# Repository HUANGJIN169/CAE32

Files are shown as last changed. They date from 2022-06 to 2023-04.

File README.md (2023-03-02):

# CAE32

CAE32 es un proyecto de construcción y desarrollo de todas las etapas de un volante para videojuegos de PC,
para el sistema operativo de GNU/Linux.

## Las etapas son:

* Diseño PCB
* Firmware
* Driver (Kernel module)
* Configuración y calibración por medio de una interfaz de usuario (GTK-3)
* Diseño de mecanismos para pedales, palanca de cambios y volante
* Diseño PCB de potencia para el control del motor de retroalimentación (FFB)

## Descripción detallada

### Microcontroladores

Para esta primera versión de Harware, se crean 3 PCB

1. Placa principal (ESP32-S3)
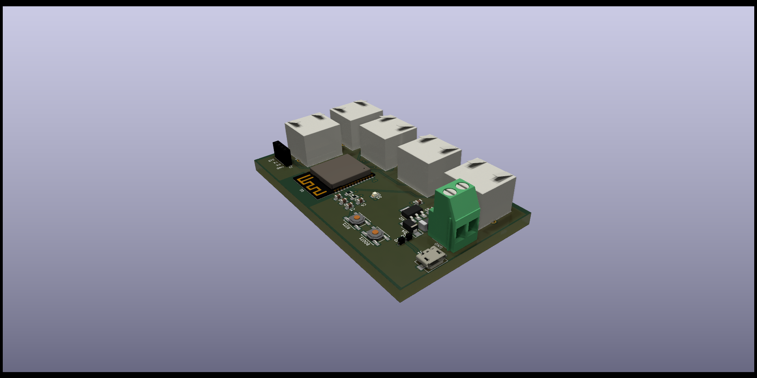
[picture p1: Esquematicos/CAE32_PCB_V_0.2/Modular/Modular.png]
Modular

2. Placa para la captura de señales analogicas (STM32G070KBT6)
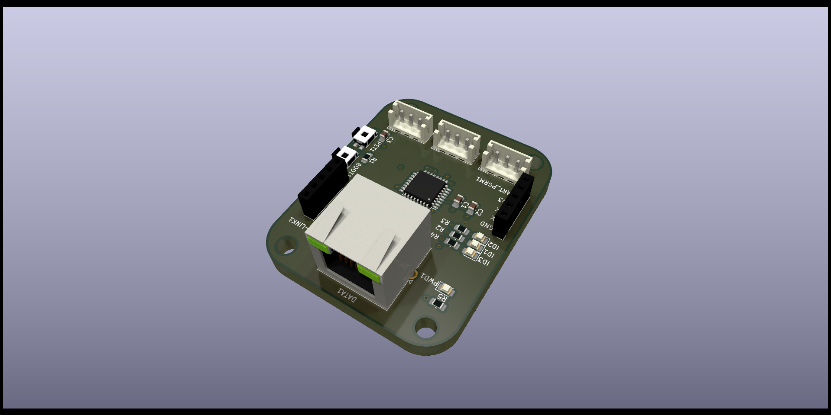
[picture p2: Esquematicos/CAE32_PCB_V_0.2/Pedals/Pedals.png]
Señales

3. Placa con el sensor hall (MT9105ET)
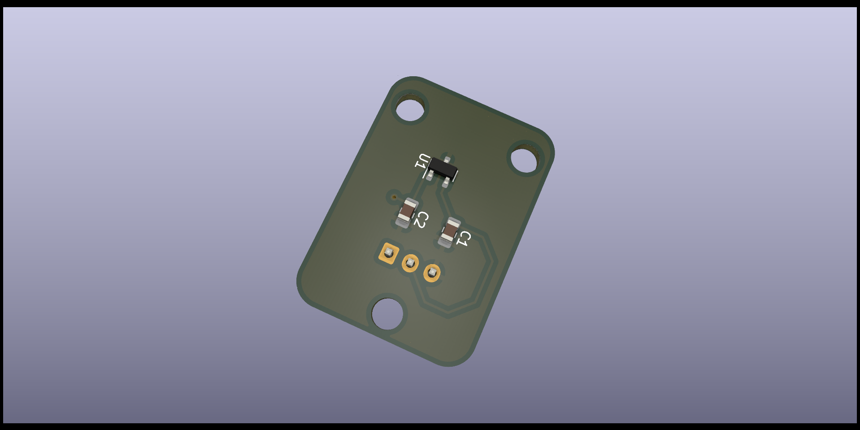
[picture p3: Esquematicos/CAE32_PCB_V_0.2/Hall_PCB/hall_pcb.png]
hall


### Firmware

Estoy usando el framework de Espressif (ESP-IDF)

Se usa el microcontrolador STM32G070KBT6, en conjunto con el software
STM32CubeIDE y para programarlo es necesario la utilidad STM32CubeProgrammer,
ademas de una conexión con un "USB-UART bridge"

### Interfaz de usuario

La interfaz está desarrollada con el framework (GTK 3), esta permitirá hacer configuraciones, como por ejemplo:

* Visualización de los datos gráficamente y textual (consola)
* Tipo de transmisión (Manual, Automática, Secuencial, custom) **De forma nativa**
* Límites de los pedales, sensibilidad 
* Tipo de pedal
	* Entrada analógica (Potenciómetro, efecto hall)
	* Entrada SPI,I2c (Célula de carga)
* Actualización de firmware

Diseño de interfaz hasta el momento.

**Para compilar el proyecto puedes usar el contenedor o construirlo en tu sistema(cumpliendo con las dependencias),
revisa la wiki para mas información**

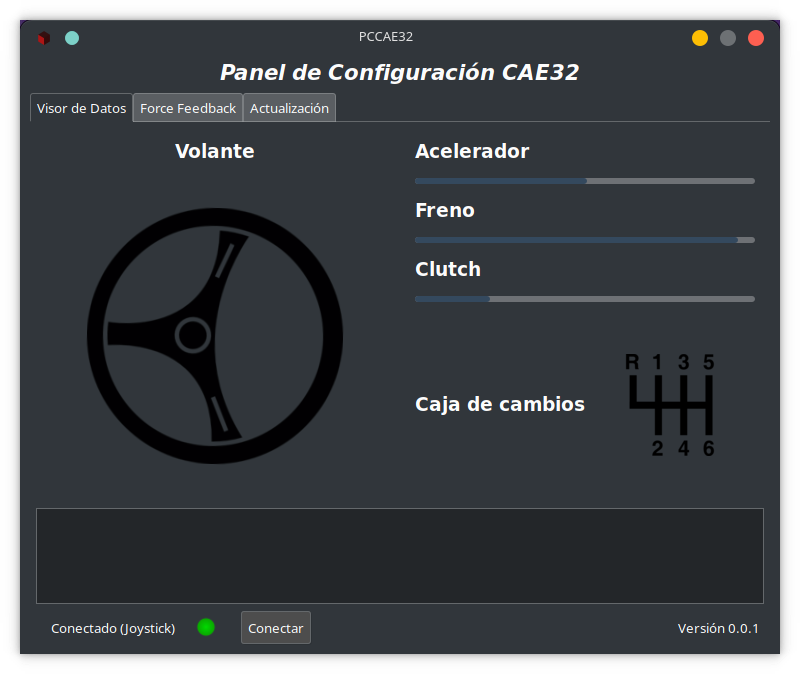
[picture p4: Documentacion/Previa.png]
interfaz


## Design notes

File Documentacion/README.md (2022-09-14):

# Descripción general para simular el movimiento de pedales
* El objetivo de realizar este componente(indicador de grados) es para hacer pruebas automatizadas. Haciendo una simulación de los movimientos realizados a la hora de conducir
* Con una retroalimentación tanto como física como digital (Mostrando los valores en la terminal)
* Ademas en el futuro este mismo componente se podría usar para mostrar las revoluciones del motor o velocidad, en general el estado de alguna características del auto
## Pasos para simular "pedales" 

### 1. Configurar el encoder magnético (AS5600) que se encarga de obtener el angulo del iman 
- Este encoder se programa por medio de comunicación i2c para leer y escribir a diferentes registros
- Requiere de mover el indicador manualmente al angulo mínimo y máximo
### 2. Constantemente convertir el valor analógico a grados para conocer su posición
- Es necesario que siempre se este ejecutando una tarea que este revisando los grados actuales y compararlos con los grados deseados
### 3. Controlar el motor DC
- Como el motor simulara el movimiento, por ejemplo, el del un volante, este tiene que girar en un sentido o en el otro, con diferentes velocidades y cambios repentinos de sentido de giro
- Se puede aplicar un control PID

## [Materiales necesarios para crear este componente](Hardware%20componentes%20eléctricos/Indicador%20de%20grados.md)
## [Obtención de grados](Firmware/Obtención%20de%20grados.md)

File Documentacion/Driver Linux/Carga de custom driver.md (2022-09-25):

https://stackoverflow.com/questions/37427731/use-custom-driver-over-an-existing-driver
https://docs.kernel.org/driver-api/usb/writing_usb_driver.html
https://docs.kernel.org/driver-api/driver-model/binding.html

## USB Host-Side API Model[¶](https://docs.kernel.org/driver-api/usb/usb.html#usb-host-side-api-model "Permalink to this heading")
Host-side drivers for USB devices talk to the “usbcore”

USB device drivers actually bind to interfaces, not devices. Think of them as “interface drivers”, though you may not see many devices where the distinction is important. _Most USB devices are simple, with only one function, one configuration, one interface, and one alternate setting._

-   The Linux USB API supports synchronous calls for control and bulk messages. It also supports asynchronous calls for all kinds of data transfer, using request structures called “URBs” (USB Request Blocks).

In `include/uapi/linux/usb/ch9.h` you will find the USB data types defined in chapter 9 of the USB specification. These data types are used throughout USB, and in APIs including this host side API, gadget APIs, usb character devices and debugfs interfaces. That file is itself included by `include/linux/usb/ch9.h`, which also contains declarations of a few utility routines for manipulating these data types; the implementations are in `drivers/usb/common/common.c`.

### /dev/bus/usb/BBB/DDD[¶](https://docs.kernel.org/driver-api/usb/usb.html#dev-bus-usb-bbb-ddd "Permalink to this heading")

Use these files in one of these basic ways:

-   _They can be read,_ producing first the device descriptor (18 bytes) and then the descriptors for the current configuration. See the USB 2.0 spec for details about those binary data formats. You’ll need to convert most multibyte values from little endian format to your native host byte order, although a few of the fields in the device descriptor (both of the BCD-encoded fields, and the vendor and product IDs) will be byteswapped for you. Note that configuration descriptors include descriptors for interfaces, altsettings, endpoints, and maybe additional class descriptors.
    
-   _Perform USB operations_ using _ioctl()_ requests to make endpoint I/O requests (synchronously or asynchronously) or manage the device. These requests need the `CAP_SYS_RAWIO` capability, as well as filesystem access permissions. Only one ioctl request can be made on one of these device files at a time. This means that if you are synchronously reading an endpoint from one thread, you won’t be able to write to a different endpoint from another thread until the read completes. This works for _half duplex_ protocols, but otherwise you’d use asynchronous i/o requests.

You could check this by changing your final `grep` into `grep --color=always` and piping into `hexdump`, which will show all the unprintable characters and the ones interpreted by your terminal.

In `include/uapi/linux/usb/ch9.h` you will find the USB data types defined in chapter 9 of the USB specification. These data types are used throughout USB, and in APIs including this host side API, gadget APIs, usb character devices and debugfs interfaces. That file is itself included by `include/linux/usb/ch9.h`, which also contains declarations of a few utility routines for manipulating these data types; the implementations are in `drivers/usb/common/common.c`.

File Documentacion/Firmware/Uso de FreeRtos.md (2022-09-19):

# FreeRtos
Para controlar el tiempo de ejecución de cada función es necesario usar FreeRtos, ya que se pueden crear tareas **(_Tasks_)** de manera periódicas además de añadirles un nivel de prioridad a cada una de estas.

**Nota:** Otra manera de manejar el orden de ejecución de funciones, es por medio de interrupciones, **Ejemplo:** se asigna una interrupción cuando se sobrecarga un temporizador **_(Timer)_**  para poder ejecutar una función sería algo equivalente a las tareas periódicas  .

## Las tareas que deben ejecutarse son las siguientes
1. Obtención del valor a enviar, en este caso los grados, pero para obtener mas precisión se usara el valor directo del ADC debido a abarca un rango mas amplio 0->4095 **8Bits** pero se puede aumentar hasta **11Bits**, mientras que los grados 0->360
2. Envió de la trama de datos por protocolo USB 
3. Recepción de datos para aplicar un feedback al volante
4. Aplicar el control PID al motor, con los datos recién recibidos 

|Número de tarea|Características|
|--|--|
|1|Debe de ejecutarse 4 veces consecutivamente cada cierto periodo de tiempo|
|2,3,4|Tarea periódica para tener un dispositivo sincrónico|
 
## Queue o no Queue
Parece que la mejor forma de pasar datos entre tareas es por medio de queues, ya que es menos probable que te des un disparo en el pie ya que no es necesario el uso de punteros, aunque también se pueden usar.

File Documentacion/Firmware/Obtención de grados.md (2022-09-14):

# Obtención de grados
### El encoder magnético ofrece 3 maneras de obtener el ángulo
* Comunicación i2c leyendo dos registros
* Variación de voltaje en el pin OUT proporcional al ángulo **Se usará esta opción**
* Variación de ciclo de trabajo en cada pulso que es proporcional al ángulo
### Para usar estas opciones es necesario realizar una configuración por medio de comunicación i2c
**Nota:** Es posible programarlo solo usando el pin OUT pero la configuración es casi nula

### Para obtener mas información de este encoder aquí esta la [hoja de datos del AS5600](https://datasheet.lcsc.com/lcsc/2004071505_AMS-AS5600-ASOT_C499458.pdf) 

## Proceso de configuración
La configuración para esta aplicación depende del movimiento de los pedales, normalmente no excede los **360°** (mas de una vuelta) de rotación, así que para aprovechar la mayor resolución (el valor obtenido se acercara mas al real) hay que usar solo el rango de grados necesario en este caso **260°** 

|N. Paso|Instrucciones|
|--|--|
|1|Seguir los pasos para limitar el rango máximo del angulo como se muestra [aquí](https://datasheet.lcsc.com/lcsc/2004071505_AMS-AS5600-ASOT_C499458.pdf#page=24) con un valor 2958 -> 1Bit **0B** 2Bit **8E** , estos valores se obtiene con esta [regla de 3](https://datasheet.lcsc.com/lcsc/2004071505_AMS-AS5600-ASOT_C499458.pdf#page=24)| 
|2|Seguir los pasos para elegir la posición inicial y final como se muestra [aquí](https://datasheet.lcsc.com/lcsc/2004071505_AMS-AS5600-ASOT_C499458.pdf#page=22)|
|3|Guardar la configuración permanente usando el el paso de BURN_ANGLE, mostrado en las referencias externas mostradas en los pasos anteriores|
|4|Los valores cargados para el registro CONF son: salida analógica en un rango de 10% a 90%, aunque todavía se podría mejorar la precisión haciendo unos cambios|

**Notas:** 
1. Este proceso se hace por medio de la comunicación i2c.
2. El paso numero 2 se puede hacer de dos maneras.
* Manualmente, moviendo el indicador a la parte inicial y final, en el arranque del ESP-32 presionando un botón 
* Automáticamente, usando el motor para que por un tiempo definido se mueva hasta un tope en la zona inicial, cambie de sentido y tope con la zona final 
3. El imán siempre debe de estar presente, de lo contrario no se guardaran los datos
4. Se elige un rango 10% a 90% por que el ADC del ESP-32 no puede leer voltaje menor a 0.1 V , además se usa un divisor de voltaje para disminuir el rango de voltaje superior y sea posible medir.
## Después de la configuración
**Conozco dos maneras de obtener los grados**
1. Usar interrupciones con ayuda de un timer para hacer la conversión de voltaje a grados y usar ese valor como entrada para el controlador PID
2. Usar FreeRtos y asignar como tarea,hacer la conversión de voltaje a grados para el PID
## [Aplicación de controlador PID](Control%20PID.md)
## [Uso de FreeRtos](Uso%20de%20FreeRtos.md)

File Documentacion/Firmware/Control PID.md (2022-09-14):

# Control PID
El controlador PID permitirá un control estable para apuntar a los grados deseados.

A grandes rasgos será una función que tome de entrada los grados actuales, aplique una ecuación y retorna una variable con la cual se podrá variar la velocidad del motor DC
>Ejemplo :
>Cuando se acerquen los grados actuales a los grados deseados, este disminuirá el ciclo de trabajo PWM(se puede interpretar como que disminuye la velocidad) y no sobrepasara los grados deseados

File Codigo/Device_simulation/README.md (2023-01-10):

# Device Class Definition for Human Interface Devices (HID) Version1.11

**Si queres ver como fue el desarrollo del driver y herramientas, te recomiendo que veas este [archivo](Bitácora.md)**

### Enlaces de información 

[Device Class Definition for Human Interface Devices (HID) Version1.11](https://www.usb.org/sites/default/files/hid1_11.pdf)
[HID Usage Tables FOR Universal Serial Bus (USB)](https://usb.org/sites/default/files/hut1_3_0.pdf)

- Debido a que es muy extenso la documentación relacioanad al descriptor de un dispositivo 
de interfaz humana, tomaré nota de cada tema y llenare los huecos tomando como ejemplo a CAE32

## Capacidades de CAE32

Descripción simple de como funcionan los sensores que se encuentran en un 
volante para videojuegos

### Palanca de cambios

En los autos reales solo existen dos estados en los que puede encontrar una velocidad:

* Velocidad acoplada
* Velocidad no acoplada

Esto se puede comparar con una señal digital la cual solo puede estar en dos estados "1" y "0"
lógico, con lo que se puede usar un botón 

**Nota:** Tecnicamente los estados en los que puede estar una transmisión estandar son: el numero
de velocidades del auto mas uno (neutral)

**Ejemplo: Transmisión de auto estandar de 8 velocidades representada en una trama de bits**

|bit|7|6|5|4|3|2|1|0|
|--|--|--|--|--|--|--|--|--|
|Estado|0|0|0|0|1|0|0|0|

Tomando en cuenta que el bit 0 es la reversa y la primera corresponde con el bit 1, segunda con
el bit 2, y así sucesivamente

Se entiende que se encuentra en la tercera marcha, y para identificar neutral sería que todas
las marchas se encuentren desacopladas, exactamente como en la vida real.

|bit|7|6|5|4|3|2|1|0|
|--|--|--|--|--|--|--|--|--|
|Estado|0|0|0|0|0|0|0|0|

### Pedales

Los pedales funcionan dependiendo en cuanta fuerza se aplique y el recorrido de estos

Por ejemplo si quisiera revolucionar el motor al 50% debo de presionar el acelerador hasta la mitad
del recorrido (en dado que este se comporte de manera lineal), 25%=1/4, 
54%=un poco mas de la mitad, etc.

**Ejemplo: Comportamiento del acelerador en relación con la velocidad elegida**

Pos

Y a que tipo de señal se compara en el mundo de la electrónica: a la señal analogica

**Ejemplo: Señal analógica en relación con el tiempo**

SenA

Y la forma en la que se representa en el mundo digital, es usando un ADC (Analog to DC converter),
el rango de valores que toma depende de su resolución que puede ir desde 8bits hasta 24bits o 
incluso mas, está resolución se podría notar en la sensibilidad de este, lo que se traduce a
un mayor control del auto

**Nota:** la resolución maxima y el formato permitido también depende del juego

**Ejemplo: Valor de un pedal representado en 8bits | Rango de valores (0,255)**

* Valor:183, equivalente a presionar 71% del recorrido total 

|bit|7|6|5|4|3|2|1|0|
|--|--|--|--|--|--|--|--|--|
|Estado|1|0|1|1|0|1|1|1|

### Volante

El comportamiento de un volante es similar al de un pedal, solo que este puede hacer transiciones,
con la diferencia que este puede o no tener un tope físico, esto depende del tipo de transductor
usado, este puede ser un potenciometro, sensor de efecto hall, etc

Desconozco como se toma el valor en el videojuego, lo mas seguro es que se comporte como un pedal,
donde 127 (con una resolución de 8bits) sea el centro y dependiendo de los grados de giro 
de elegidos (normalmente los volantes de entrada cuentan con 900°) los divide y por ejemplo una 
diferencia de 102 se toma como una vuelta completa.

## Resumen

El espacio en bits requeridos para el HID 
 
* 8 bits para la palanca de cambios | 1 bit por cada velocidad o 3 bits, reprentando el valor de la marcha en
binario **Ejemplo** Primera=0x001, Quinta=0x101, Ocatava=0x111 etc

* 32 bits para pedales y volante | 8 bits por cada pedal o volante 

# 5. Operational Model

## 5.1 Device Descriptor Structure

En el nivel mas alto, el descriptor incluye dos tablas

* Información referida al "Device Descriptor"
* Información referida al "String Descriptor"

La estructura de un descriptor principalmente se compone de 

- Class
- Subclass
- Vendor
- Product
- Version
 
Siguiendo este esquema

estructura 

Para un "HID class device" el tipo de "Class" no esta definido al nivel de "Device descriptor"
entonces la clase esta definida en el "Interface descriptor"

## 5.2 Report Descriptor

Aunque los Descriptores seán ilustrados con un diagrama de flujo estos en realidad estan compuestos
en piezas de información conocidos como "Item" 

Un "Item" es una pieza unica de información

## 5.3 Generic Item Format

Un "Item" es un pieza de información acerca del dispositivo, todos los "items" tienen un prefijo del
tamaño de un byte y contiene "item tag, item type, item size" etiqueta, tipo y tamaño

|bits|23-16|15-8|7-0|
|--|--|--|--|
|Partes|[data]|[data]|btag,btype,bsize|
|Bytes|2|1|0|

Un "Item" puede contener "optional item data", el tamaño de la porcion de la "data" de un "item"
esta determinada por el tipo fundamental de dato, existen dos tipos basicos de "item": "short and
long", si un item es corto, "its optional data size may be 0,1,2 or 4 bytes" si un item es largo
el valor de bSize siempre sera 2

**Ejemplo**

|bits|258-24|23-16|15-8|70|
|--|--|--|--|--|
|Partes|[data]|blongItemTag|bDataSize|111/11/10|
|Bytes|3-258|2|1|0|

## 5.4 Item Parser

EL controlador de clases del HID contiene un analizador (Parser) usado par encontrar "items" 
en el reporte de descripción

Este analizador colecta el estado de cada item conocido con forma avanza el descriptor,
y los guarda una tabla de estado de items

La tabla de estados de items contiene el estado de cada item individualmente

Desde el punto de vista del analizador, el dispositivo de clases HID se ve así

analizado

Cuando algunos items son encontrados, el contenido de la tabla de estados de items es movida,
estos items incluyen todos lo "Main,Push and Pop" items

Cuando un item "Main" es encontrado, una nueva estructura de reporte es alocada e inicializada
con la actual tabla de estado de items.

Todos los items Locales son removidos de la tabla de estados de items, pero los items Globales
se quedan, de esta forma los items globales definen los valores por defecto de los subsecuentes nuevos items Main

Un dispositivo con muchos controles similares, por ejemplo 6 ejes, necesitaría definir los items 
globales solo una vez en el primer item Main.

**Nota:** Los items Main son asociados con una colección en el orden que en los que ellos fueron
declarados, una nueva colección empieza cuando el analizador llega a un item de colección,
El analizador asocia una colección con todos los items Main definidos entre el item colección y 
el siguiente item fin de colección

Cuando un item Push es encotrado, la tabla de estado de items es copiado y colocada en el "stack"
para su futura recuperación

Cuando un item Pop es encontrado, la tabla de estado de items es remplazada con el "top table from
the stack" 

**Ejemplo**

`Unit (Meter), Unit Exponent (-3), Push, Unit Exponent (0)`

Cuando el analizador alcanza el item Push, coloca la unidad de los items en milimetros `10^-3 
metros`"on the stack", el siguiente item cambia el estado de item de la tabla a unidad de metros 
`10^0 metros`

El Analizador es requerido para analizar todo el reporte del descriptor para encontrar todos los 
items Main, esto es necesario en orden para analizar los reportes enviados por el dispositivo

## 5.5 Usages

Mientras un reporte de descriptor describe el formato de los datos

**Ejemplo** 3 campos de 8 bits

Una etiqueta "Usage" define que se debe de hacer con eso dato

**Ejemplo** entradas "x,y" y "z"

Un reporte de descriptor puede tener multiples etiquetas de "usages"

Existe una correspondencía una-a-una entre "usages" y controles, un control "usage" definido en el 
descriptor

Una matriz indica que cada campo del reporte del descriptor representa varios controles físicos 

Cada control quiza tenga atributos como "usage" asignados a ellos

**Ejemplo** una matriz de 4 botones puede tener una unica etiqueta "usage" por cada botón

Un "usage" es interpretado como un valor de 32 bits sin signo donde el mayor orden, los primeros
16 bits definen el "usage page" y los otros menores 16 bits definen la identificación del uso
"Usage ID" 

"Usage IDS" son usados para seleccionar "usages" individualmente en una "usage Page"

## 5.6 Reports

Una reporte es sinonimo de transferencía
 
Una transferencía quiza se compone de multiple paquetes con un maximo de 
* 8bits para dispositivos de baja velocidad
* 64bits para dispositivos de alta velocidad

Muchos dispositivos generan reportes, o transferencias , retornando una estructura en donde cada
campo de datos es secuencialmente representado, sin embargo, algunos dispositivos tienen multiples 
estructuras de reporte, en un solo endpoint, que cada uno representa solo unos cuantos campos de 
datos

**Ejemplo** Un teclado con apuntador integrado, puede representar reportes independientes de
pulsación de tecla y subsecuente datos del apuntador en el mismo endpoint

"Report ID items" son usados para indicar que campo de dato son representados en cada estructura
de reporte

Un "Report ID" item asigna una etiqueta de un 1 byte identificado con un prefijo en cada transferencia 
de reporte

Si no existe una etiqueta de "Report ID item" esta presente en el reporte del descriptor,
se asume que solo existe un reporte de estructura con "Input, Outpur and Feature" esta presente
y junto ellos representan todos los datos de disposito

**Nota** Solo reportes de "input" son enviados via "interrupt in pipe", reporte de rasgos y salidas
deben ser reportados por el host via "control pipe" o a opcional "interrupr out pipe"

si un dispositivo tien multiples estructuras de reporte, todas las trasnferencias de datos
inician con un prefijo de identificador de 1-byte que indican que estructura de reporte aplica
con la transferencía

Esto permite a "class driver" que distinga los datos del apuntador y del teclado examinando 
el prefijo de transferencía __esto hace referencia al ejemplo anterior del teclado con apuntador__

## 5.7 Strigs

Es una colección de datos que contienen texto asociado y está es opcional

No es necesario usar el item "usage"

El string descriptor contiene una lista de texto para el dispositivo

## 5.8 Format of MultiByte Numeric Values

## 6.2.2 Report descriptor

### 1. Explicación del primer ejemplo 

Este ejemplo muestra como se acomodan los bit en base al report descriptor

```
Report size (3)

Report count (2)

Input

Report size (8)

Input

Output 
```

* Lo que entiendo es que todos los reportes se toman como items globales
* Se "sobreescriben" dependiendo del orden en que estos se encuentran acomodados

* Report size: se identifica como el tamaño de bits
* Report count: Se identifica como el numero de campos 
* Iput y Output se identifica como el tipo de dato

Comportamiento del ejemplo

```
Report size (3)

Report count (2)

Input 
```

1. Asigna dos campos de entrada con un tamaño de 3 bits

` Report size (8)`

2. Se "sobreescribe" el tamaño de bit de los subsecuentes tipos de datos

**Esto es equivalente a realizar esta acción con los siguientes tipos de datos**

```
Report count (2)

Report size (8)

Input

Output 
```

3. Asigna dos campos, proveniente de la segunda linea además de asignar una de entrada y salida 
de salida con un tamaño de 8 bits

Un reporte de descriptor puede contener muchos main items

Un reporte de descriptor debe incluir cada uno de los siguientes items para describit el control de los datos
(todos los demas items son opcionales)

- Input(Output or Feature)
- Usage
- Usage Page
- Logical Minimum
- Logical Maximum
- Report Size
- Report Count

**Ejemplo** Los siguiente items son usados para definir un mouse con tres botones, en este caso, todos los main
items son precedentes de los items globales como "usage,report count or report size" (cada linea es un nuevo item

```
Usage Page (Generic Desktop), ;Use the Generic Desktop Usage Page
Usage (Mouse),
	Collection (Application), ;Start Mouse collection
	Usage (Pointer),
	Collection (Physical), ;Start Pointer collection
		Usage Page (Buttons)
		Usage Minimum (1),
		Usage Maximum (3),
		Logical Minimum (0),
		Logical Maximum (1), ;Fields return values from 0 to 1
		Report Count (3),
		Report Size (1), ;Create three 1 bit fields (button 1, 2, & 3)
		Input (Data, Variable, Absolute), ;Add fields to the input report.
		Report Count (1),
		Report Size (5), ;Create 5 bit constant field
		Input (Constant), ;Add field to the input report
		Usage Page (Generic Desktop),
		Usage (X),
		Usage (Y),
		Logical Minimum (-127),
		Logical Maximum (127), ;Fields return values from -127 to 127
		Report Size (8),
		Report Count (2), ;Create two 8 bit fields (X & Y position)
		Input (Data, Variable, Relative), ;Add fields to the input report
End Collection, ;Close Pointer collection
End Collection ;Close Mouse collection
```

### Comprobación y análisis del ejemplo en uhid.c

```c
 static unsigned char rdesc[] = {
         0x05, 0x01,     /* USAGE_PAGE (Generic Desktop) */
         0x09, 0x02,     /* USAGE (Mouse) */
         0xa1, 0x01,     /* COLLECTION (Application) */
         0x09, 0x01,             /* USAGE (Pointer) */
         0xa1, 0x00,             /* COLLECTION (Physical) */
         0x85, 0x01,                     /* REPORT_ID (1) */
         0x05, 0x09,                     /* USAGE_PAGE (Button) */
         0x19, 0x01,                     /* USAGE_MINIMUM (Button 1) */
         0x29, 0x03,                     /* USAGE_MAXIMUM (Button 3) */
         0x15, 0x00,                     /* LOGICAL_MINIMUM (0) */
         0x25, 0x01,                     /* LOGICAL_MAXIMUM (1) */
         0x95, 0x03,                     /* REPORT_COUNT (3) */
         0x75, 0x01,                     /* REPORT_SIZE (1) */
         0x81, 0x02,                     /* INPUT (Data,Var,Abs) */
         0x95, 0x01,                     /* REPORT_COUNT (1) */
         0x75, 0x05,                     /* REPORT_SIZE (5) */
         0x81, 0x01,                     /* INPUT (Cnst,Var,Abs) */
         0x05, 0x01,                     /* USAGE_PAGE (Generic Desktop) */
         0x09, 0x30,                     /* USAGE (X) */
         0x09, 0x31,                     /* USAGE (Y) */
         0x09, 0x38,                     /* USAGE (WHEEL) */
         0x15, 0x81,                     /* LOGICAL_MINIMUM (-127) */
         0x25, 0x7f,                     /* LOGICAL_MAXIMUM (127) */
         0x75, 0x08,                     /* REPORT_SIZE (8) */
         0x95, 0x03,                     /* REPORT_COUNT (3) */
         0x81, 0x06,                     /* INPUT (Data,Var,Rel) */
         0xc0,                   /* END_COLLECTION */
         0xc0,           /* END_COLLECTION */
         0x05, 0x01,     /* USAGE_PAGE (Generic Desktop) */
         0x09, 0x06,     /* USAGE (Keyboard) */
         0xa1, 0x01,     /* COLLECTION (Application) */
         0x85, 0x02,             /* REPORT_ID (2) */
         0x05, 0x08,             /* USAGE_PAGE (Led) */
         0x19, 0x01,             /* USAGE_MINIMUM (1) */
         0x29, 0x03,             /* USAGE_MAXIMUM (3) */
         0x15, 0x00,             /* LOGICAL_MINIMUM (0) */
         0x25, 0x01,             /* LOGICAL_MAXIMUM (1) */
         0x95, 0x03,             /* REPORT_COUNT (3) */
         0x75, 0x01,             /* REPORT_SIZE (1) */
         0x91, 0x02,             /* Output (Data,Var,Abs) */
         0x95, 0x01,             /* REPORT_COUNT (1) */
         0x75, 0x05,             /* REPORT_SIZE (5) */
         0x91, 0x01,             /* Output (Cnst,Var,Abs) */
         0xc0,           /* END_COLLECTION */
};
```
Para enteder el descriptor es bastante sencillo en caso de que todos seán "short items", 
ya que estos tienen un rango de 0 a 4 bytes de longitud 

Aunque por el momento no entiendo completamente cuando hay que usar las colecciones

Lo que se dice en la documentación es prestar especial atención al tipo de item,
ya que subsecuentemente sigue el dato

En el ejemplo de se ve obvserva como se escribe en mayuscula el tipo de 
item seguido de su valor entre parentesis

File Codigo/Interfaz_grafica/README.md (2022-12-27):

# Interfaz prelimar del visor de datos

Para compilar el proyecto es necesario todos los requisitos para GTK y **CMake**

Estos los puedes encontrar [aquí (GTK)](https://www.gtk.org/docs/installations/)

Sigue los pasos para instalar CMake dependiendo de tu distro

Instrucciones

```bash
cd Interfaz\ GTK/
mkdir build
cd build
cmake .. && make
```

VisorDeDatos


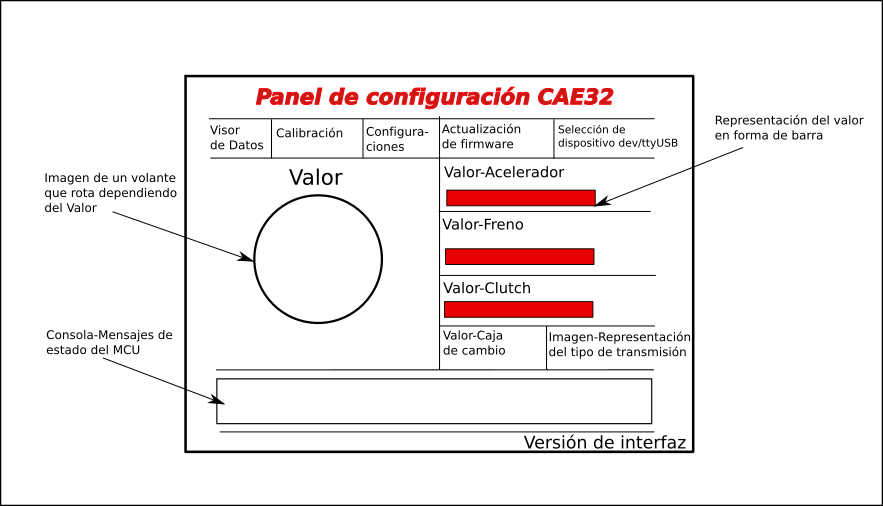
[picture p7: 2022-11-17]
Documentacion/VisorDeDatos.png

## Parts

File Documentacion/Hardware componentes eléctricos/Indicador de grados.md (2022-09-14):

# Indicador de grados
Los componentes eléctricos necesarios para construir este indicador de grados son los siguientes:
### 1. Motor genérico 
* Este motor es fácil de conseguir y su costo es bajo a comparación de un servo motor o un motor a pasos
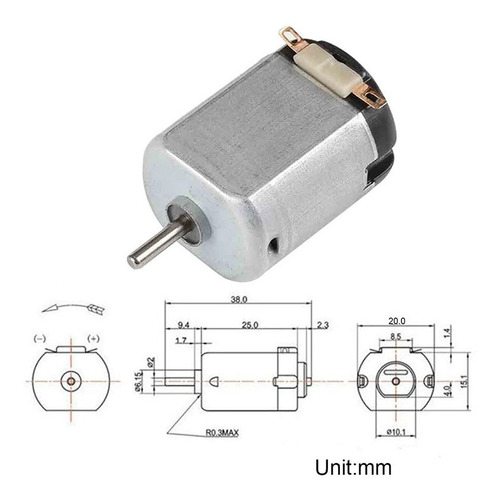
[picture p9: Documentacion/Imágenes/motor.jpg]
motor

* Se desarrolla un modelo 3D de este en FreeCad para facilitar los ensambles 
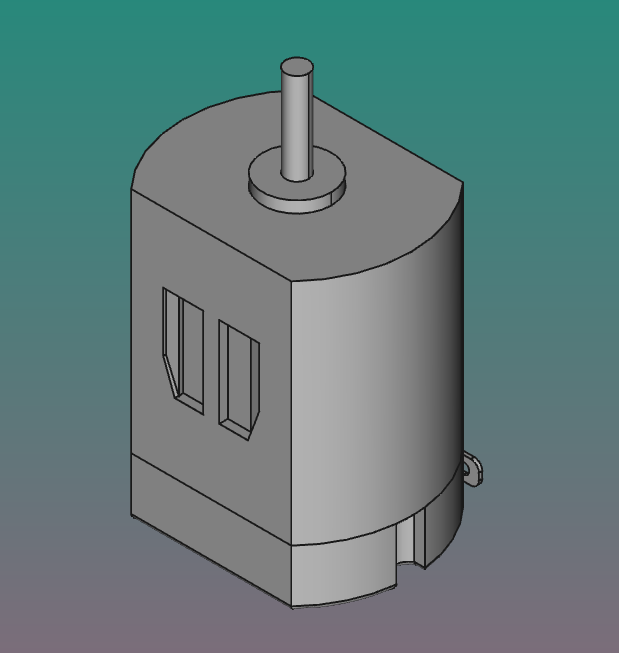
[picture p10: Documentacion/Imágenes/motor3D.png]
Motor 3D

### 2. Modulo AS5600 
* Se usa este mismo modelo 

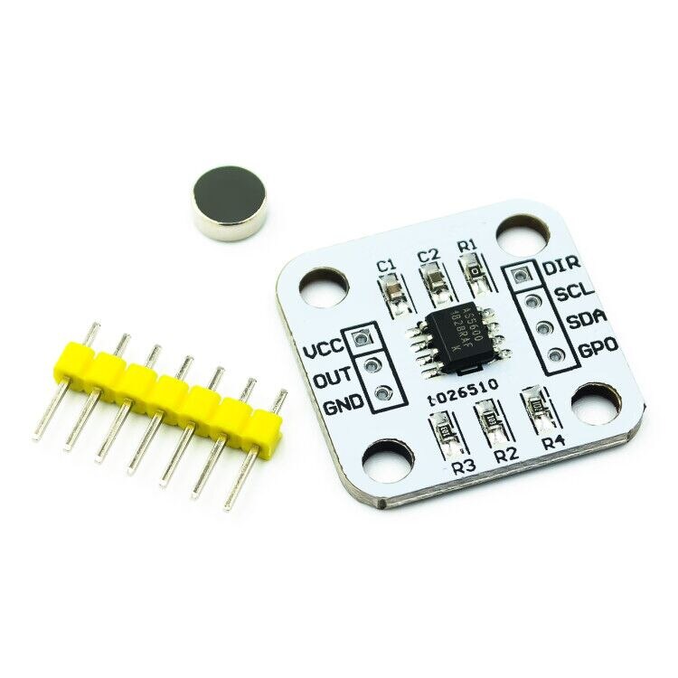
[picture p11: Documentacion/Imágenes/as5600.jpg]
AS5600


### 3. Puente H
* Este componente se encarga de manejar el voltaje que llega a las terminales del motor DC, es posible controlar dos motores DC simultáneamente con este driver
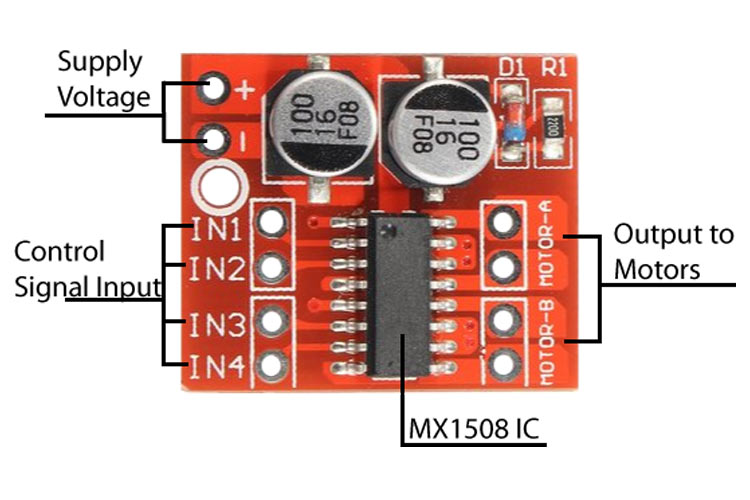
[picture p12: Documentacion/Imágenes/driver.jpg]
Driver


* Aunque se puede usar cualquier otro o directamente el arreglo de transistores, pero esta en ti tomar medidas de precaución para evitar dañar el microcontrolador.
* El ciclo de trabajo tendrá que variar, dependiendo del voltaje y corriente de entrada, por lo cual se tiene modificar el código.

### 4. Fuente de alimentación
* Se usa 2.4V  a 1.5A, con este voltaje se realizaron las pruebas pero es posible usar hasta 7V
* **Ademas se usa un motor reductor fabricado en impresión 3D lo puedes encontrar [aquí](../Elementos%20Mecánicos/Indicador%20de%20grados/Piezas%203D.md)**

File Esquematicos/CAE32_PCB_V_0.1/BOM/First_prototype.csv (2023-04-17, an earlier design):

Part name | LCSC part | Quantity | Price(US Dollars) | Availability
ESP32-S3-WROOM-1-N4 | C2913197 | 1 | 3.4046 | 287
onsemi NCP51460SN33T1G | C233715 | 1 | 0.73 | 2548
SSP1117-3.3v | C277892 | 1 | 0.0634 | 61225
ME7660CS1G | C88402 | 1 | 0.32 | 7365
Connector_USB:USB_Micro-B_Amphenol_10118194_Horizontal | C132563 | 2 | 0.21 | 20800
AD7791BRMZ | C495323 | 1 | 4.9 | 5980
74HC4051 | C2943297 | 1 | 0.24 | 2225
MT9105ET | C967861 | 3 | 0.41 | 5500

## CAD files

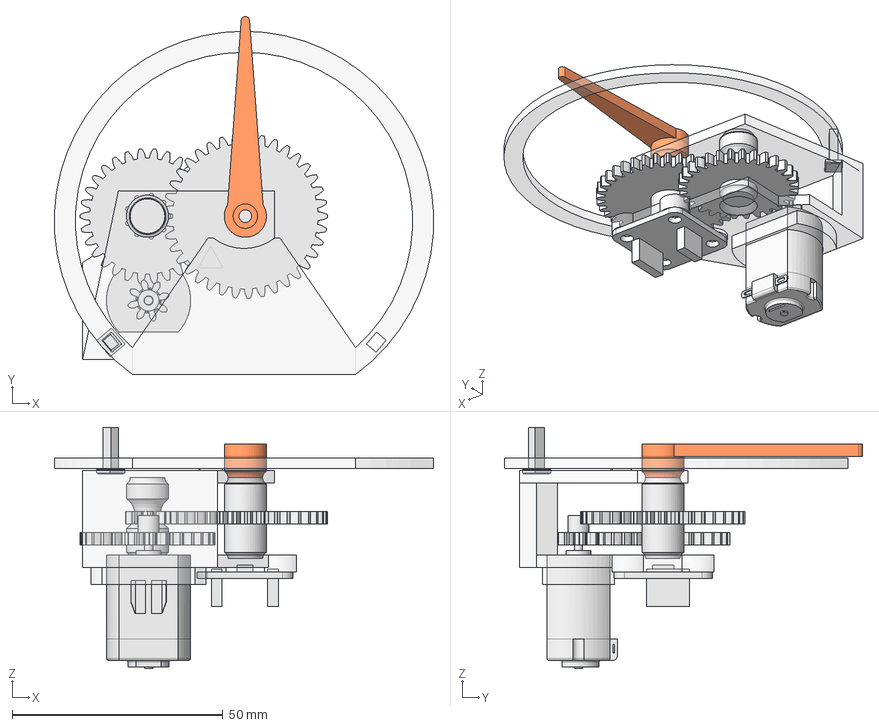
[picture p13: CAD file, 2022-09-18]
Mecanismos/Archivos_freecad/Simulación_de_pedales/Modelo_1/Ensamble.FCStd
89.9 x 84.9 x 57.2 mm
intermedio_001
EngraneApuntador_001
motores_001
engraneMotriz_001
Modulo_as5600_001
medidor_001
apuntador_001
tope_001

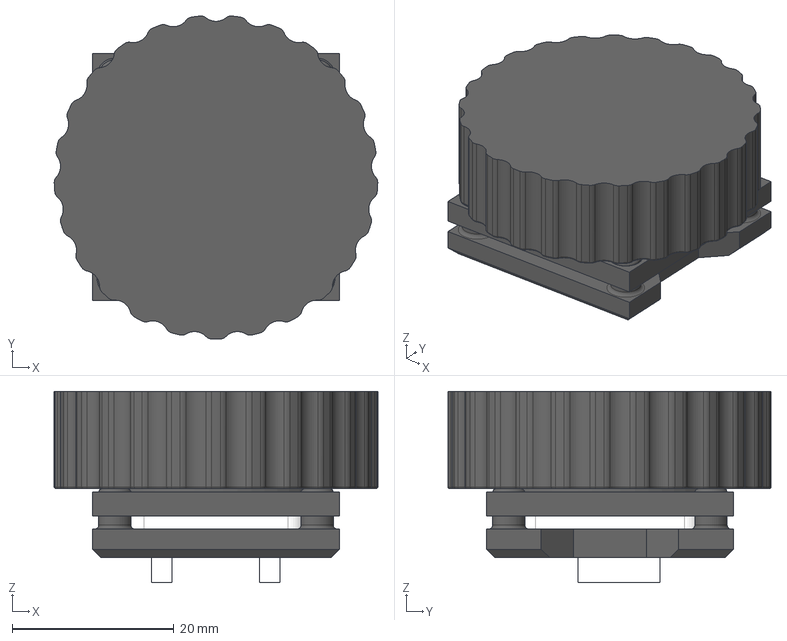
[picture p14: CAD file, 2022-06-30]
Mecanismos/Archivos_freecad/Banco_de_pruebas_AS5600/Ensamble_modulo_as5600/Ensamble.FCStd
40.0 x 39.9 x 23.6 mm
Modulo_as5600_001
iman_001
Base_iman_bal_001
Copia de Indicador_de_grados_001
Base_modulo_001

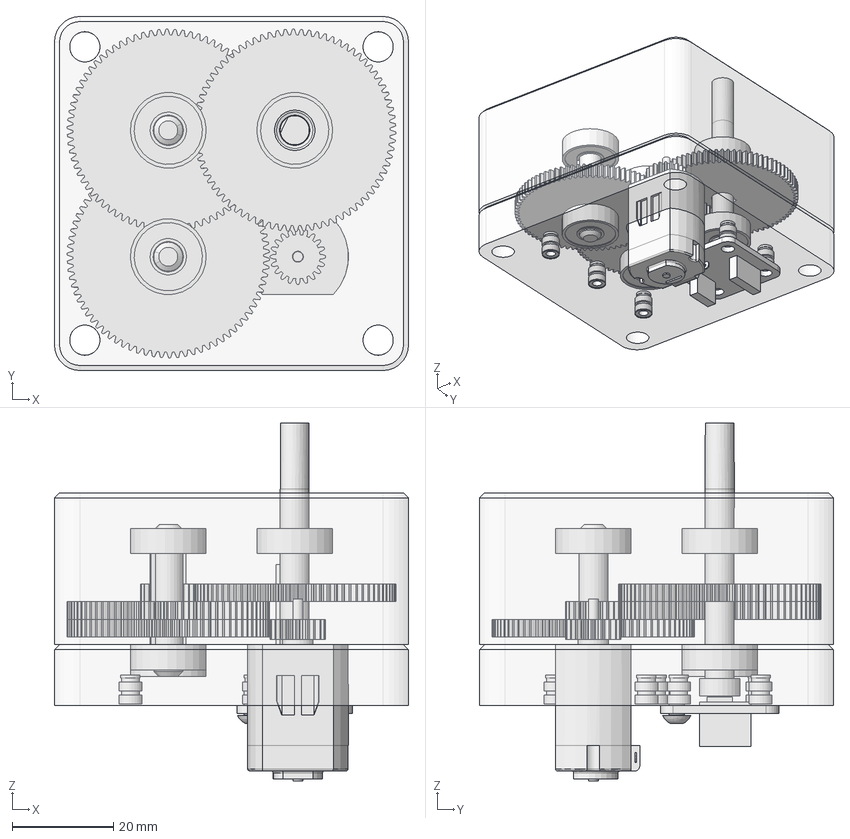
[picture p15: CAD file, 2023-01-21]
Mecanismos/Archivos_freecad/D#2/Ensamble.FCStd
70.0 x 70.0 x 70.7 mm
case0_001
Modulo_as5600_001
motores_001
M3-Insert_001
M3-Insert_002
M3-Insert_003
M3-Insert_004
M3-Insert_005
M3-Insert_006
M3-Insert_007
M3-Insert_008
case1_001
Balero_Parametrico_001
Balero_Parametrico_002
Balero_Parametrico_004
Balero_Parametrico_003
Balero_Parametrico_006
Balero_Parametrico_007
Engrane_D15_001
Engrane_Parametrico_002
Engrane_Parametrico_001
Engrane_D15_002
Engrane_Parametrico_003
Engrane_Motor_001
Eje parametrico_001
Eje parametrico_003
EJE_reatroalimentacion_001
M3x6-Screw_001

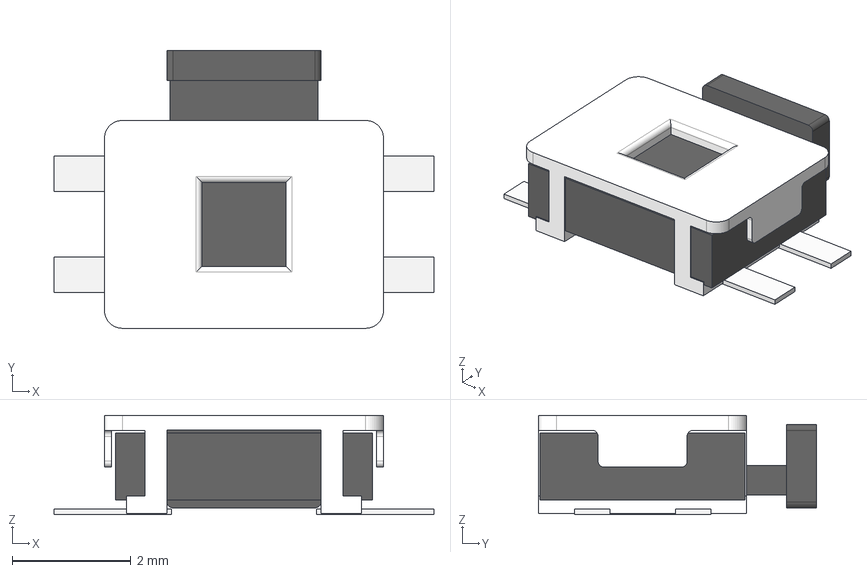
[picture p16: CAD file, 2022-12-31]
Esquematicos/Modelos_3D_Componentes_electricos/EVQPUM02K-Part.step
6.40 x 4.67 x 1.67 mm

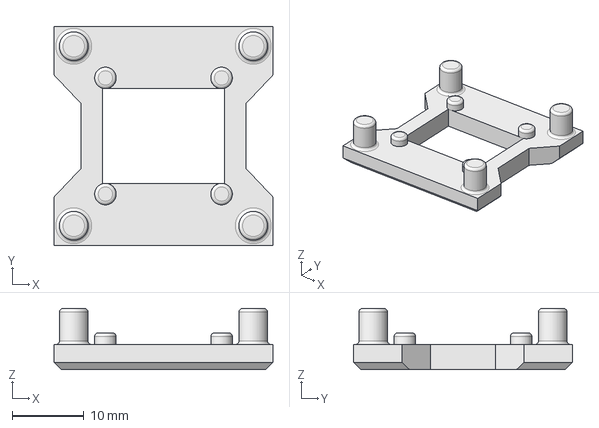
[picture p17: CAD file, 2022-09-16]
Mecanismos/Archivos_freecad/Banco_de_pruebas_AS5600/Ensamble_modulo_as5600/Base_modulo.FCStd
30.5 x 30.5 x 8.50 mm

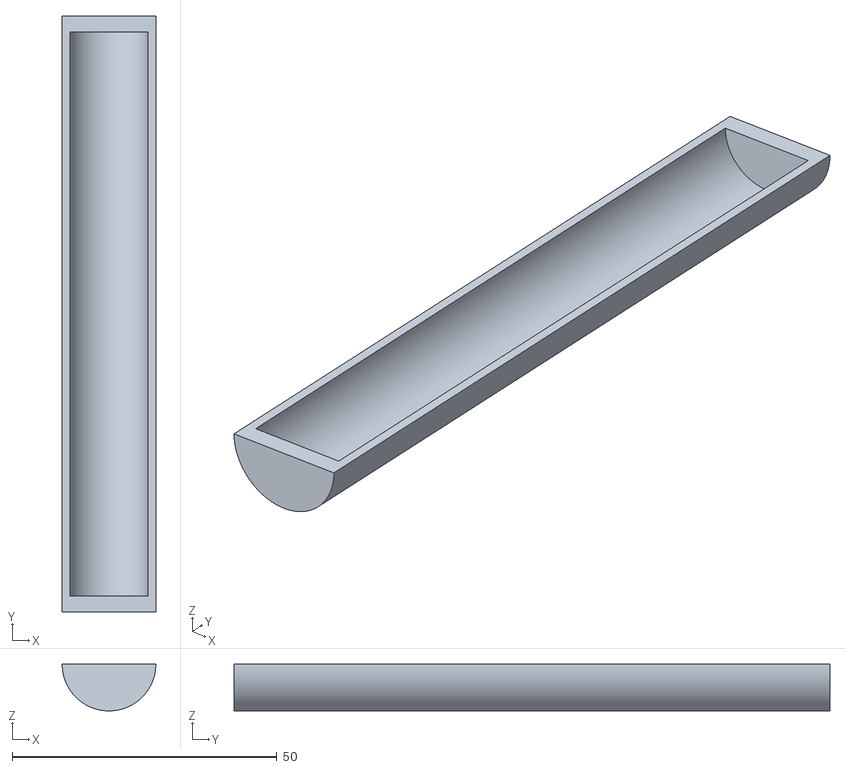
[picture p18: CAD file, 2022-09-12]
Mecanismos/Archivos_freecad/Case_para_pilas/portapilas-Body.stl
17.7 x 112.5 x 8.85

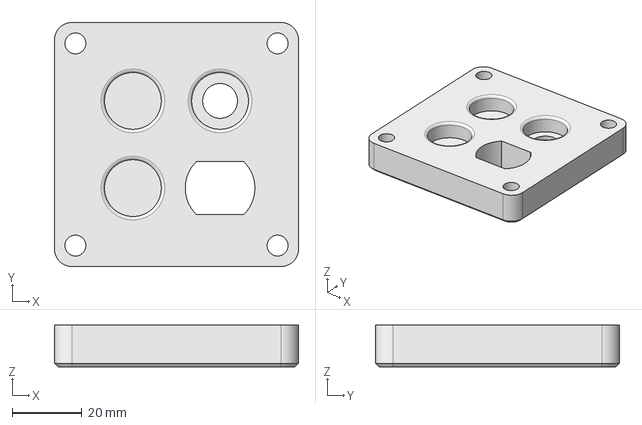
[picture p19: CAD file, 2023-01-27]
Mecanismos/Archivos_freecad/D#2/case0.FCStd
70.0 x 70.0 x 12.0 mm

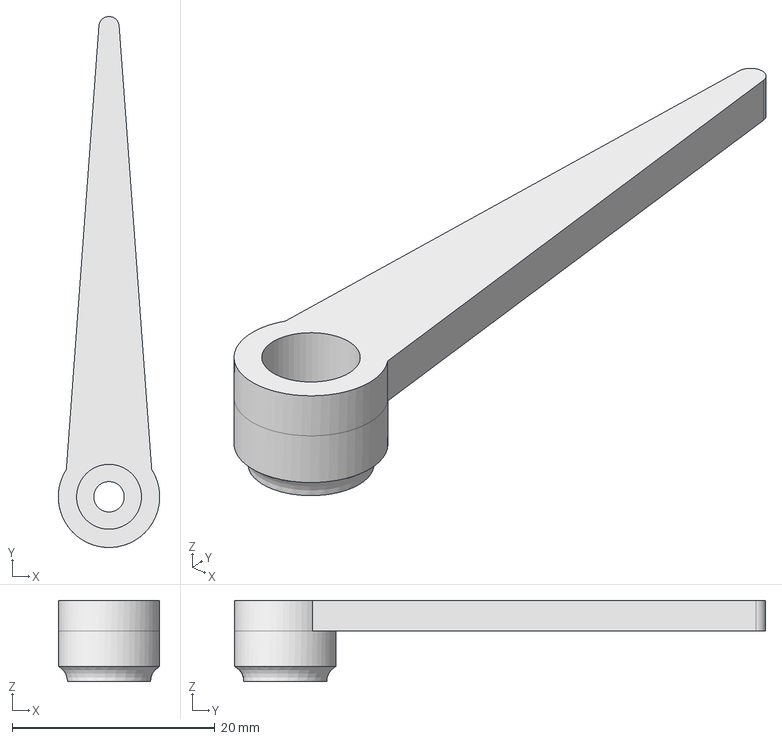
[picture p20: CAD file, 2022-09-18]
Mecanismos/Archivos_freecad/Simulación_de_pedales/Modelo_1/apuntador.FCStd
10.00 x 52.3 x 8.00 mm

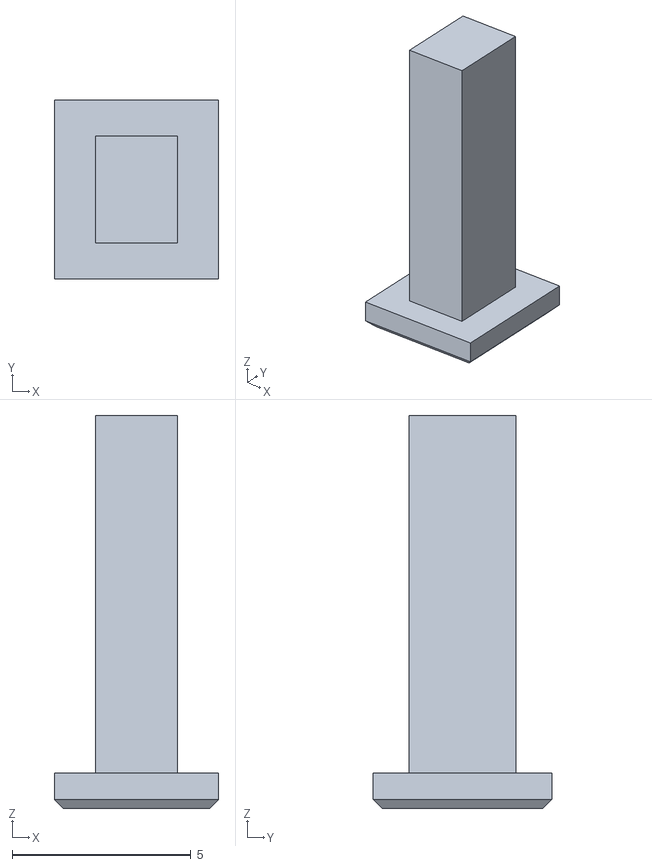
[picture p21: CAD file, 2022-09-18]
Mecanismos/Archivos_freecad/Simulación_de_pedales/Modelo_1/stl/tope-Body.stl
4.60 x 5.00 x 11.0

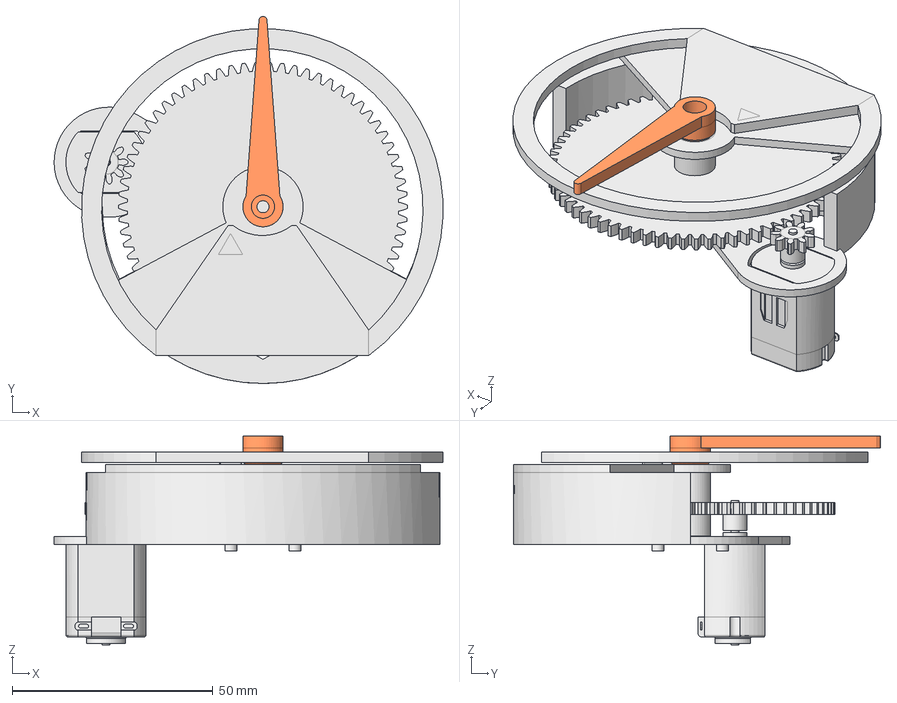
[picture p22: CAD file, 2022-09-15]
Mecanismos/Archivos_freecad/Simulación_de_pedales/Modelo_2/ens.FCStd
96.8 x 91.3 x 52.0 mm
frame_001
engrane_001
motores_001
engraneMotriz_001
apuntador_001
medidor_001

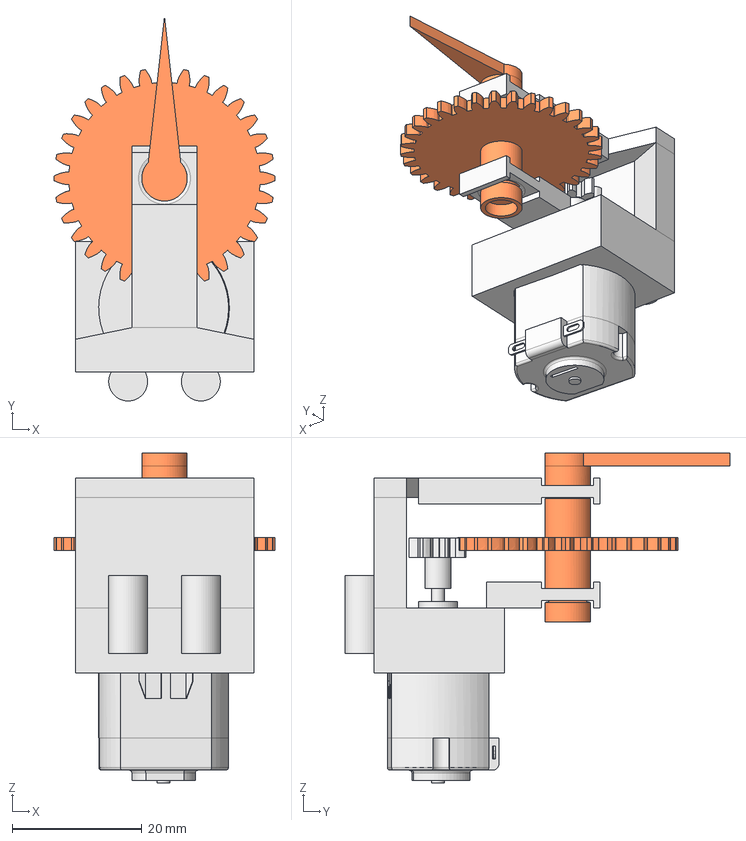
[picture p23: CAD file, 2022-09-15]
Mecanismos/Archivos_freecad/Simulación_de_pedales/Modelo_3/ens.FCStd
34.0 x 59.3 x 50.8 mm
soporte_marcador2_001
marcador_003
motores_001
Engrane_motor_V2_001

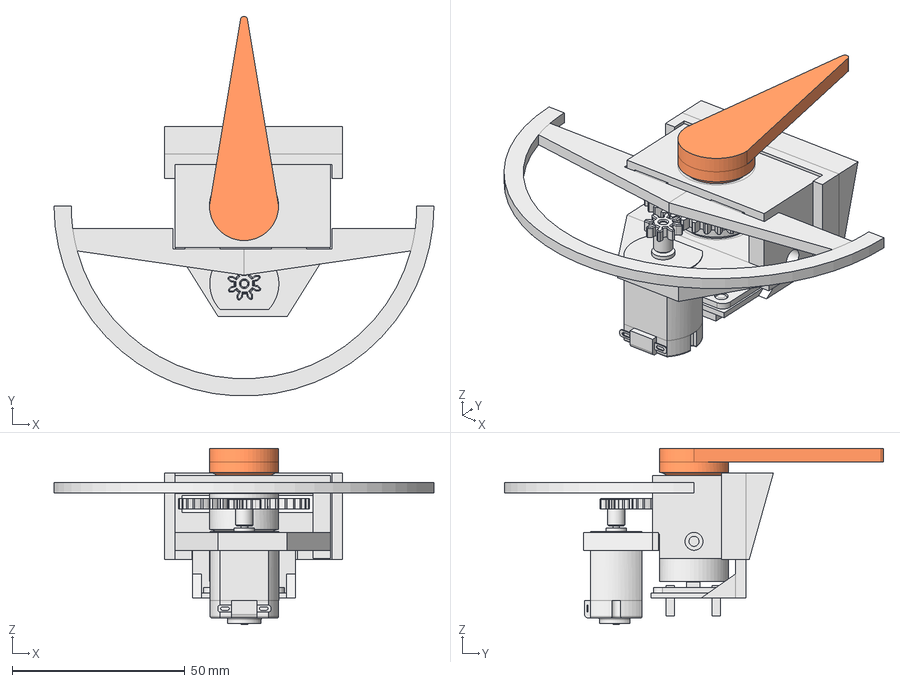
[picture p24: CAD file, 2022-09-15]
Mecanismos/Archivos_freecad/Simulación_de_pedales/Modelo_4/ens.FCStd
110.0 x 109.8 x 51.0 mm
apuntador_001
union_apuntador_001
porta_iman_001
soporteuno_001
motores_001
Modulo_as5600_001
engrane_motor_001
Copia de soportedos_001
soporte_iman_001
display_001
soporte_genereal_001

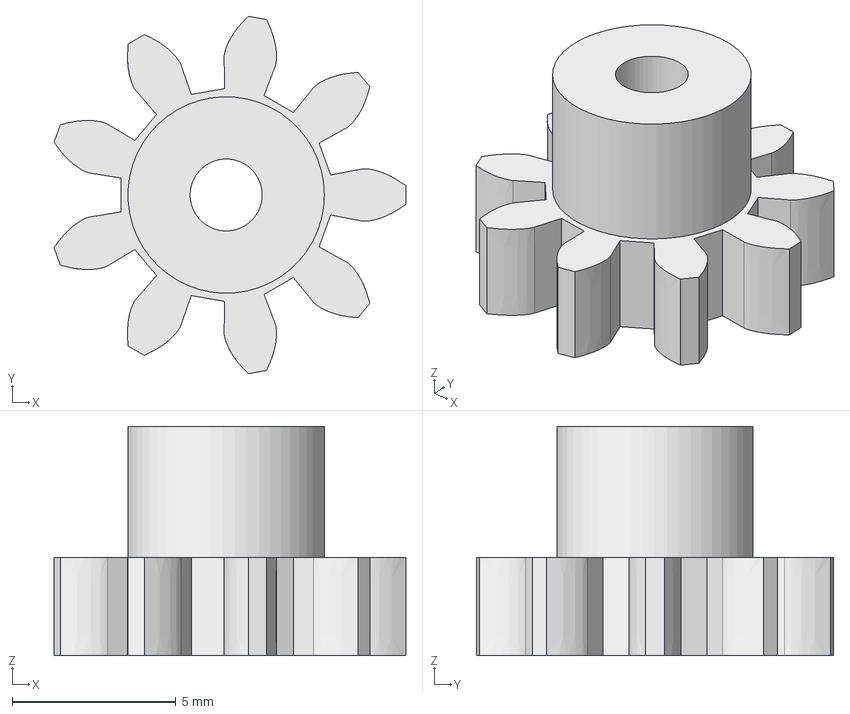
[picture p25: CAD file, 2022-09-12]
Mecanismos/Archivos_freecad/Simulación_de_pedales/Piezas_frecuentes/engraneMotriz.FCStd
10.8 x 10.9 x 7.00 mm

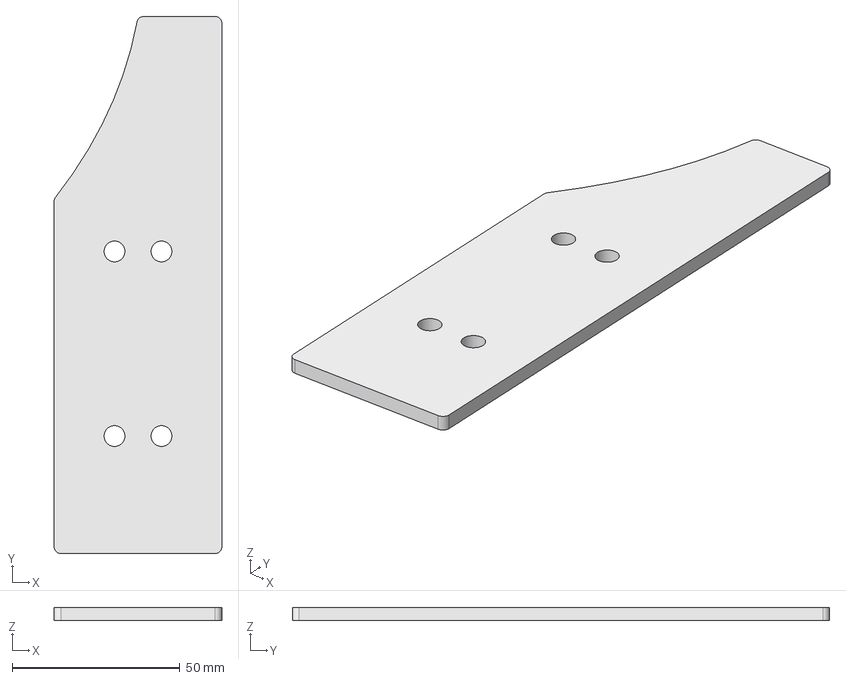
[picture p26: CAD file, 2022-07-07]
Mecanismos/Archivos_freecad/Sistema_mecanico_pedales/Pedales/accelerador.FCStd
50.0 x 160.0 x 4.00 mm

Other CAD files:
Mecanismos/Archivos_STL/D#2/EJE_reatroalimentacion-Body.3mf.amf
Mecanismos/Archivos_STL/Modulo_AS5600_p/Struct_1.stl
Mecanismos/Shifter/amf/soporte-Body.amf
Mecanismos/Shifter/Tapa.FCStd
Esquematicos/CAE32_PCB_V_0.2/Disenos_de_componentes_electricos/Modelos3d/Freecad/fusible.FCStd
Esquematicos/CAE32_PCB_V_0.2/Disenos_de_componentes_electricos/Modelos3d/step/fusible-Part.step
Esquematicos/CAE32_PCB_V_0.2/Hall_PCB/CutPcbLayout/edges.FCStd
Esquematicos/CAE32_PCB_V_0.2/Pedals/CutPcbLayout/layout.FCStd
Esquematicos/Modelos_3D_Componentes_electricos/EVQPUM02K.FCStd
Mecanismos/Archivos_STL/D#2/Eje_engrane.amf
Mecanismos/Archivos_STL/D#2/EngraneD15.amf
Mecanismos/Archivos_STL/D#2/EngraneD50.amf
Mecanismos/Archivos_STL/D#2/Engrane_Motor.amf
Mecanismos/Archivos_STL/D#2/Engrane_Parametrico-BodyPocket.amf
Mecanismos/Archivos_STL/D#2/espaciador-Body.amf
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

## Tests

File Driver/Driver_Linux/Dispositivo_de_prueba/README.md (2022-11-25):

# Device Class Definition for Human Interface Devices (HID) Version1.11

**Si queres ver como fue el desarrollo del driver y herramientas, te recomiendo que veas este [archivo](Bitácora.md)**

### Enlaces de información 

[Device Class Definition for Human Interface Devices (HID) Version1.11](https://www.usb.org/sites/default/files/hid1_11.pdf)
[HID Usage Tables FOR Universal Serial Bus (USB)](https://usb.org/sites/default/files/hut1_3_0.pdf)

- Debido a que es muy extenso la documentación relacioanad al descriptor de un dispositivo 
de interfaz humana, tomaré nota de cada tema y llenare los huecos tomando como ejemplo a CAE32

## Capacidades de CAE32

Descripción simple de como funcionan los sensores que se encuentran en un 
volante para videojuegos

### Palanca de cambios

En los autos reales solo existen dos estados en los que puede encontrar una velocidad:

* Velocidad acoplada
* Velocidad no acoplada

Esto se puede comparar con una señal digital la cual solo puede estar en dos estados "1" y "0"
lógico, con lo que se puede usar un botón 

**Nota:** Tecnicamente los estados en los que puede estar una transmisión estandar son: el numero
de velocidades del auto mas uno (neutral)

**Ejemplo: Transmisión de auto estandar de 8 velocidades representada en una trama de bits**

|bit|7|6|5|4|3|2|1|0|
|--|--|--|--|--|--|--|--|--|
|Estado|0|0|0|0|1|0|0|0|

Tomando en cuenta que el bit 0 es la reversa y la primera corresponde con el bit 1, segunda con
el bit 2, y así sucesivamente

Se entiende que se encuentra en la tercera marcha, y para identificar neutral sería que todas
las marchas se encuentren desacopladas, exactamente como en la vida real.

|bit|7|6|5|4|3|2|1|0|
|--|--|--|--|--|--|--|--|--|
|Estado|0|0|0|0|0|0|0|0|

### Pedales

Los pedales funcionan dependiendo en cuanta fuerza se aplique y el recorrido de estos

Por ejemplo si quisiera revolucionar el motor al 50% debo de presionar el acelerador hasta la mitad
del recorrido (en dado que este se comporte de manera lineal), 25%=1/4, 
54%=un poco mas de la mitad, etc.

**Ejemplo: Comportamiento del acelerador en relación con la velocidad elegida**

Pos

Y a que tipo de señal se compara en el mundo de la electrónica: a la señal analogica

**Ejemplo: Señal analógica en relación con el tiempo**

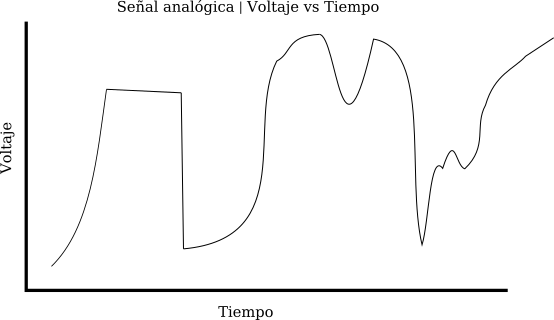
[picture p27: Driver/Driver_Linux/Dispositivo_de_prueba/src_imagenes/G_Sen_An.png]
SenA


Y la forma en la que se representa en el mundo digital, es usando un ADC (Analog to DC converter),
el rango de valores que toma depende de su resolución que puede ir desde 8bits hasta 24bits o 
incluso mas, está resolución se podría notar en la sensibilidad de este, lo que se traduce a
un mayor control del auto

**Nota:** la resolución maxima y el formato permitido también depende del juego

**Ejemplo: Valor de un pedal representado en 8bits | Rango de valores (0,255)**

* Valor:183, equivalente a presionar 71% del recorrido total 

|bit|7|6|5|4|3|2|1|0|
|--|--|--|--|--|--|--|--|--|
|Estado|1|0|1|1|0|1|1|1|

### Volante

El comportamiento de un volante es similar al de un pedal, solo que este puede hacer transiciones,
con la diferencia que este puede o no tener un tope físico, esto depende del tipo de transductor
usado, este puede ser un potenciometro, sensor de efecto hall, etc

Desconozco como se toma el valor en el videojuego, lo mas seguro es que se comporte como un pedal,
donde 127 (con una resolución de 8bits) sea el centro y dependiendo de los grados de giro 
de elegidos (normalmente los volantes de entrada cuentan con 900°) los divide y por ejemplo una 
diferencia de 102 se toma como una vuelta completa.

## Resumen

El espacio en bits requeridos para el HID 
 
* 8 bits para la palanca de cambios | 1 bit por cada velocidad o 3 bits, reprentando el valor de la marcha en
binario **Ejemplo** Primera=0x001, Quinta=0x101, Ocatava=0x111 etc

* 32 bits para pedales y volante | 8 bits por cada pedal o volante 

# 5. Operational Model

## 5.1 Device Descriptor Structure

En el nivel mas alto, el descriptor incluye dos tablas

* Información referida al "Device Descriptor"
* Información referida al "String Descriptor"

La estructura de un descriptor principalmente se compone de 

- Class
- Subclass
- Vendor
- Product
- Version
 
Siguiendo este esquema

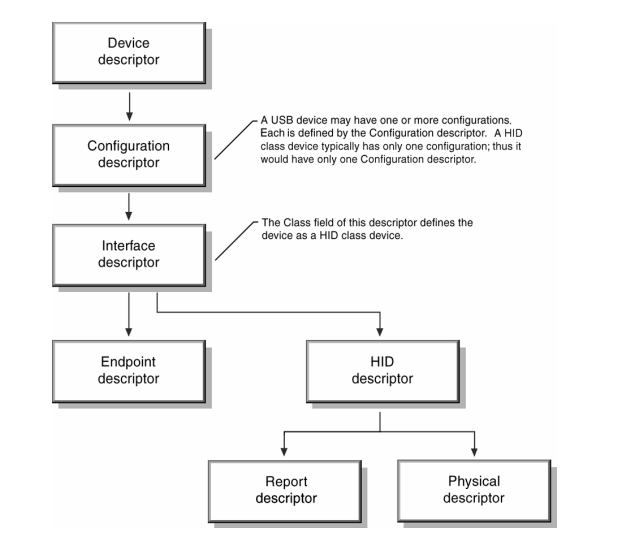
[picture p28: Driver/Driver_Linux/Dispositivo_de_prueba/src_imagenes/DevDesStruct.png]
estructura
 

Para un "HID class device" el tipo de "Class" no esta definido al nivel de "Device descriptor"
entonces la clase esta definida en el "Interface descriptor"

## 5.2 Report Descriptor

Aunque los Descriptores seán ilustrados con un diagrama de flujo estos en realidad estan compuestos
en piezas de información conocidos como "Item" 

Un "Item" es una pieza unica de información

## 5.3 Generic Item Format

Un "Item" es un pieza de información acerca del dispositivo, todos los "items" tienen un prefijo del
tamaño de un byte y contiene "item tag, item type, item size" etiqueta, tipo y tamaño

|bits|23-16|15-8|7-0|
|--|--|--|--|
|Partes|[data]|[data]|btag,btype,bsize|
|Bytes|2|1|0|

Un "Item" puede contener "optional item data", el tamaño de la porcion de la "data" de un "item"
esta determinada por el tipo fundamental de dato, existen dos tipos basicos de "item": "short and
long", si un item es corto, "its optional data size may be 0,1,2 or 4 bytes" si un item es largo
el valor de bSize siempre sera 2

**Ejemplo**

|bits|258-24|23-16|15-8|70|
|--|--|--|--|--|
|Partes|[data]|blongItemTag|bDataSize|111/11/10|
|Bytes|3-258|2|1|0|

## 5.4 Item Parser

EL controlador de clases del HID contiene un analizador (Parser) usado par encontrar "items" 
en el reporte de descripción

Este analizador colecta el estado de cada item conocido con forma avanza el descriptor,
y los guarda una tabla de estado de items

La tabla de estados de items contiene el estado de cada item individualmente

Desde el punto de vista del analizador, el dispositivo de clases HID se ve así

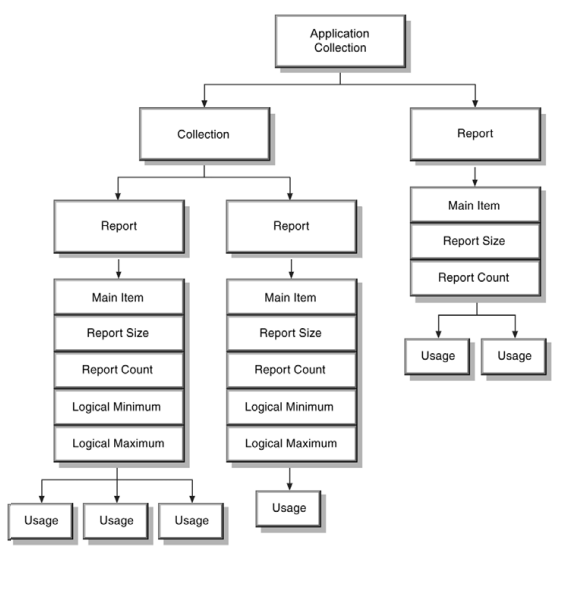
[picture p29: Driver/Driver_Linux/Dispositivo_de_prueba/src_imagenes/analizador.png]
analizado


Cuando algunos items son encontrados, el contenido de la tabla de estados de items es movida,
estos items incluyen todos lo "Main,Push and Pop" items

Cuando un item "Main" es encontrado, una nueva estructura de reporte es alocada e inicializada
con la actual tabla de estado de items.

Todos los items Locales son removidos de la tabla de estados de items, pero los items Globales
se quedan, de esta forma los items globales definen los valores por defecto de los subsecuentes nuevos items Main

Un dispositivo con muchos controles similares, por ejemplo 6 ejes, necesitaría definir los items 
globales solo una vez en el primer item Main.

**Nota:** Los items Main son asociados con una colección en el orden que en los que ellos fueron
declarados, una nueva colección empieza cuando el analizador llega a un item de colección,
El analizador asocia una colección con todos los items Main definidos entre el item colección y 
el siguiente item fin de colección

Cuando un item Push es encotrado, la tabla de estado de items es copiado y colocada en el "stack"
para su futura recuperación

Cuando un item Pop es encontrado, la tabla de estado de items es remplazada con el "top table from
the stack" 

**Ejemplo**

`Unit (Meter), Unit Exponent (-3), Push, Unit Exponent (0)`

Cuando el analizador alcanza el item Push, coloca la unidad de los items en milimetros `10^-3 
metros`"on the stack", el siguiente item cambia el estado de item de la tabla a unidad de metros 
`10^0 metros`

El Analizador es requerido para analizar todo el reporte del descriptor para encontrar todos los 
items Main, esto es necesario en orden para analizar los reportes enviados por el dispositivo

## 5.5 Usages

Mientras un reporte de descriptor describe el formato de los datos

**Ejemplo** 3 campos de 8 bits

Una etiqueta "Usage" define que se debe de hacer con eso dato

**Ejemplo** entradas "x,y" y "z"

Un reporte de descriptor puede tener multiples etiquetas de "usages"

Existe una correspondencía una-a-una entre "usages" y controles, un control "usage" definido en el 
descriptor

Una matriz indica que cada campo del reporte del descriptor representa varios controles físicos 

Cada control quiza tenga atributos como "usage" asignados a ellos

**Ejemplo** una matriz de 4 botones puede tener una unica etiqueta "usage" por cada botón

Un "usage" es interpretado como un valor de 32 bits sin signo donde el mayor orden, los primeros
16 bits definen el "usage page" y los otros menores 16 bits definen la identificación del uso
"Usage ID" 

"Usage IDS" son usados para seleccionar "usages" individualmente en una "usage Page"

## 5.6 Reports

Una reporte es sinonimo de transferencía
 
Una transferencía quiza se compone de multiple paquetes con un maximo de 
* 8bits para dispositivos de baja velocidad
* 64bits para dispositivos de alta velocidad

Muchos dispositivos generan reportes, o transferencias , retornando una estructura en donde cada
campo de datos es secuencialmente representado, sin embargo, algunos dispositivos tienen multiples 
estructuras de reporte, en un solo endpoint, que cada uno representa solo unos cuantos campos de 
datos

**Ejemplo** Un teclado con apuntador integrado, puede representar reportes independientes de
pulsación de tecla y subsecuente datos del apuntador en el mismo endpoint

"Report ID items" son usados para indicar que campo de dato son representados en cada estructura
de reporte

Un "Report ID" item asigna una etiqueta de un 1 byte identificado con un prefijo en cada transferencia 
de reporte

Si no existe una etiqueta de "Report ID item" esta presente en el reporte del descriptor,
se asume que solo existe un reporte de estructura con "Input, Outpur and Feature" esta presente
y junto ellos representan todos los datos de disposito

**Nota** Solo reportes de "input" son enviados via "interrupt in pipe", reporte de rasgos y salidas
deben ser reportados por el host via "control pipe" o a opcional "interrupr out pipe"

si un dispositivo tien multiples estructuras de reporte, todas las trasnferencias de datos
inician con un prefijo de identificador de 1-byte que indican que estructura de reporte aplica
con la transferencía

Esto permite a "class driver" que distinga los datos del apuntador y del teclado examinando 
el prefijo de transferencía __esto hace referencia al ejemplo anterior del teclado con apuntador__

## 5.7 Strigs

Es una colección de datos que contienen texto asociado y está es opcional

No es necesario usar el item "usage"

El string descriptor contiene una lista de texto para el dispositivo

## 5.8 Format of MultiByte Numeric Values

## 6.2.2 Report descriptor

### 1. Explicación del primer ejemplo 

Este ejemplo muestra como se acomodan los bit en base al report descriptor

```
Report size (3)

Report count (2)

Input

Report size (8)

Input

Output 
```

* Lo que entiendo es que todos los reportes se toman como items globales
* Se "sobreescriben" dependiendo del orden en que estos se encuentran acomodados

* Report size: se identifica como el tamaño de bits
* Report count: Se identifica como el numero de campos 
* Iput y Output se identifica como el tipo de dato

Comportamiento del ejemplo

```
Report size (3)

Report count (2)

Input 
```

1. Asigna dos campos de entrada con un tamaño de 3 bits

` Report size (8)`

2. Se "sobreescribe" el tamaño de bit de los subsecuentes tipos de datos

**Esto es equivalente a realizar esta acción con los siguientes tipos de datos**

```
Report count (2)

Report size (8)

Input

Output 
```

3. Asigna dos campos, proveniente de la segunda linea además de asignar una de entrada y salida 
de salida con un tamaño de 8 bits

Un reporte de descriptor puede contener muchos main items

Un reporte de descriptor debe incluir cada uno de los siguientes items para describit el control de los datos
(todos los demas items son opcionales)

- Input(Output or Feature)
- Usage
- Usage Page
- Logical Minimum
- Logical Maximum
- Report Size
- Report Count

**Ejemplo** Los siguiente items son usados para definir un mouse con tres botones, en este caso, todos los main
items son precedentes de los items globales como "usage,report count or report size" (cada linea es un nuevo item

```
Usage Page (Generic Desktop), ;Use the Generic Desktop Usage Page
Usage (Mouse),
	Collection (Application), ;Start Mouse collection
	Usage (Pointer),
	Collection (Physical), ;Start Pointer collection
		Usage Page (Buttons)
		Usage Minimum (1),
		Usage Maximum (3),
		Logical Minimum (0),
		Logical Maximum (1), ;Fields return values from 0 to 1
		Report Count (3),
		Report Size (1), ;Create three 1 bit fields (button 1, 2, & 3)
		Input (Data, Variable, Absolute), ;Add fields to the input report.
		Report Count (1),
		Report Size (5), ;Create 5 bit constant field
		Input (Constant), ;Add field to the input report
		Usage Page (Generic Desktop),
		Usage (X),
		Usage (Y),
		Logical Minimum (-127),
		Logical Maximum (127), ;Fields return values from -127 to 127
		Report Size (8),
		Report Count (2), ;Create two 8 bit fields (X & Y position)
		Input (Data, Variable, Relative), ;Add fields to the input report
End Collection, ;Close Pointer collection
End Collection ;Close Mouse collection
```

### Comprobación y análisis del ejemplo en uhid.c

```
 static unsigned char rdesc[] = {
         0x05, 0x01,     /* USAGE_PAGE (Generic Desktop) */
         0x09, 0x02,     /* USAGE (Mouse) */
         0xa1, 0x01,     /* COLLECTION (Application) */
         0x09, 0x01,             /* USAGE (Pointer) */
         0xa1, 0x00,             /* COLLECTION (Physical) */
         0x85, 0x01,                     /* REPORT_ID (1) */
         0x05, 0x09,                     /* USAGE_PAGE (Button) */
         0x19, 0x01,                     /* USAGE_MINIMUM (Button 1) */
         0x29, 0x03,                     /* USAGE_MAXIMUM (Button 3) */
         0x15, 0x00,                     /* LOGICAL_MINIMUM (0) */
         0x25, 0x01,                     /* LOGICAL_MAXIMUM (1) */
         0x95, 0x03,                     /* REPORT_COUNT (3) */
         0x75, 0x01,                     /* REPORT_SIZE (1) */
         0x81, 0x02,                     /* INPUT (Data,Var,Abs) */
         0x95, 0x01,                     /* REPORT_COUNT (1) */
         0x75, 0x05,                     /* REPORT_SIZE (5) */
         0x81, 0x01,                     /* INPUT (Cnst,Var,Abs) */
         0x05, 0x01,                     /* USAGE_PAGE (Generic Desktop) */
         0x09, 0x30,                     /* USAGE (X) */
         0x09, 0x31,                     /* USAGE (Y) */
         0x09, 0x38,                     /* USAGE (WHEEL) */
         0x15, 0x81,                     /* LOGICAL_MINIMUM (-127) */
         0x25, 0x7f,                     /* LOGICAL_MAXIMUM (127) */
         0x75, 0x08,                     /* REPORT_SIZE (8) */
         0x95, 0x03,                     /* REPORT_COUNT (3) */
         0x81, 0x06,                     /* INPUT (Data,Var,Rel) */
         0xc0,                   /* END_COLLECTION */
         0xc0,           /* END_COLLECTION */
         0x05, 0x01,     /* USAGE_PAGE (Generic Desktop) */
         0x09, 0x06,     /* USAGE (Keyboard) */
         0xa1, 0x01,     /* COLLECTION (Application) */
         0x85, 0x02,             /* REPORT_ID (2) */
         0x05, 0x08,             /* USAGE_PAGE (Led) */
         0x19, 0x01,             /* USAGE_MINIMUM (1) */
         0x29, 0x03,             /* USAGE_MAXIMUM (3) */
         0x15, 0x00,             /* LOGICAL_MINIMUM (0) */
         0x25, 0x01,             /* LOGICAL_MAXIMUM (1) */
         0x95, 0x03,             /* REPORT_COUNT (3) */
         0x75, 0x01,             /* REPORT_SIZE (1) */
         0x91, 0x02,             /* Output (Data,Var,Abs) */
         0x95, 0x01,             /* REPORT_COUNT (1) */
         0x75, 0x05,             /* REPORT_SIZE (5) */
         0x91, 0x01,             /* Output (Cnst,Var,Abs) */
         0xc0,           /* END_COLLECTION */
};
```
Para enteder el descriptor es bastante sencillo en caso de que todos seán "short items", 
ya que estos tienen un rango de 0 a 4 bytes de longitud 

Aunque por el momento no entiendo completamente cuando hay que usar las colecciones

Lo que se dice en la documentación es prestar especial atención al tipo de item,
ya que subsecuentemente sigue el dato

En el ejemplo de se ve obvserva como se escribe en mayuscula el tipo de 
item seguido de su valor entre parentesis

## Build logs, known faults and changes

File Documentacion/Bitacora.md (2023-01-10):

# Dispositivo virtual

Haciendo uso de el ejemplo uhid-example, este lo puedes encontrar [aquí](https://github.com/torvalds/linux/blob/master/samples/uhid/uhid-example.c), 
con este código te muestran como es posible simular un mouse con tres botones y un teclado.

El motivo del por que estoy usando esto, es por que aún esta en desarrollo la PCB, además de conocer como funciona el descriptor HID,
que en grandes rasgos le dice las caracteristas de un dispositivo y el manejo que le debe de dar a los datos, tanto de entrada como 
salida.

El código al compilarse y ejecutarlo como **root** crea un "dispositivo virtual" que al presionar las teclas "WASD" mueve el puntero 
un poco en la dirección de la tecla correspondiente, te recomiendo que veas el link de la parte de arriba para mas información.

Para presentar este dispositivo virtual como un joystick es necesario un cambio

```c
static unsigned char rdesc[] = {
	0x05, 0x01,	/* USAGE_PAGE (Generic Desktop) */
	0x09, 0x02,	/* USAGE (Mouse) */
	0xa1, 0x01,	/* COLLECTION (Application) */
``` 
 
a

```c
static unsigned char rdesc[] = {
	0x05, 0x01,	/* USAGE_PAGE (Generic Desktop) */ //
	0x09, 0x04,	/* USAGE (Mouse) */ De esta forma se le dice que es un joystick
	0xa1, 0x01,	/* COLLECTION (Application) */
```

y si usamos una herramienta como "jstest-gtk" se ve que lo reconoce como un joystick

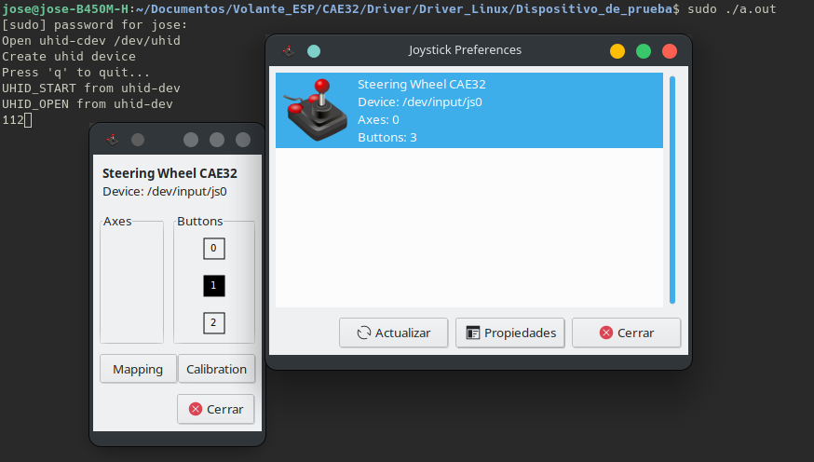
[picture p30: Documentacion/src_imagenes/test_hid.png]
Funcionamiento hid


**Nota:** Le añadí previamente un nombre personalizado en este caso "Steering Wheel CAE32", en tu caso vendra con el nombre de "test-uhid-device"

## Código

Con esta prevía introducción es hora de crear un joystick con las caracteristicas de CAE32, estas son:

* 4 ejes, para pedales y volante

* 7 botones, para las marchas, 6 marchas y reversa, la neutral se toma como "0"

**Notas**

1. Para esta primera versión de este dispositivo, los ejes tienen una resolución de 1-byte, rango de 0 a 255 o -127 a 126,
lo que puede ser poco para los estandares del momento.

2. Por el momento no se implementa el force feedback (FFB).

3. Los números con _0xnn_ son hexadecimales

### Como se observa todos los tipos de datos son de entrada, por lo cual hay que echar un vistazo, para elegir como vamos a tratar los datos

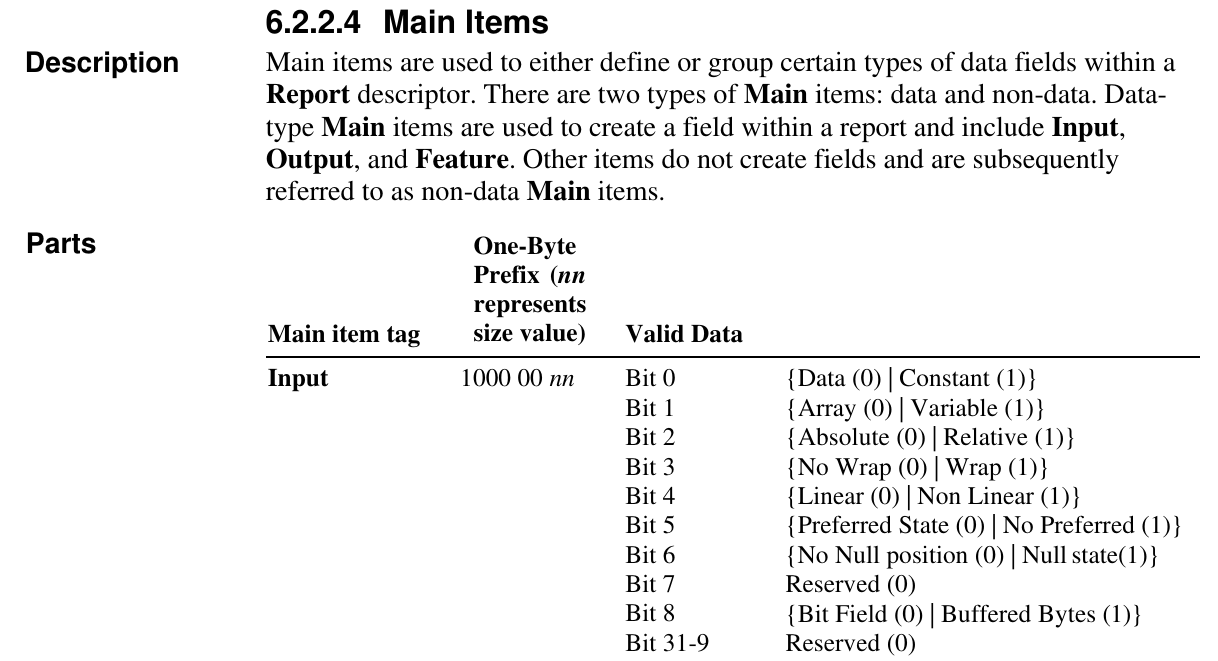
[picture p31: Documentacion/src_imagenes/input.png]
input


* Para los pedales creo que la mejor opción es escoger el bit 4 de lineal o no lineal

* Para los botones se usara el bit 1, de matriz o variable

_Al final de este apartado agregaré como queda el código_ 

### Ahora para definir el tamaño de los valores de entrada hay que usar la etiqueta "Report Size"  

* Pedales=8 bits=0x08

* Botones=1 bit=0x01

### Si existen varios datos de entradas similares, como son los botones y pedales se pueden declarar con la siguiente etiqueta "Report Count"

* Pedales=3 campos =0x03

* Botones=8 campos =0x08u
### Ya tenemos definido que tipo y la cantidad de datos de entrada, pero aún falta definir para que lo vamos a usar

La manera en que se usan los datos dependen de varias etiquetas como:

* "Usage Page"

* "Usage"

* "Logical Minimum"

* "Logical Maximum"

* "Usage Minimum"

* "Usage Maximum"

**Nota:** Existen mas tipos de etiquetas de uso, pero estas son las basicas.

Para definir que es un joystick hay que buscar en "las Usage Pages" y lo encontramos en "Generic Desktop Page" con un valor de **0x04**

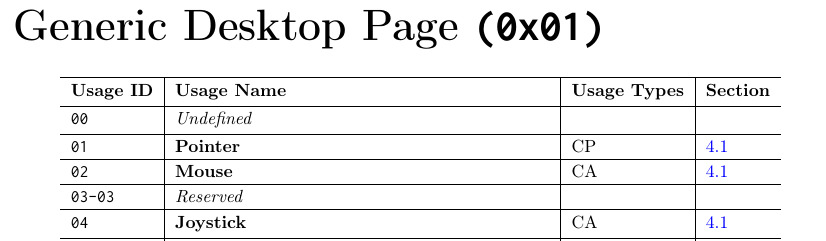
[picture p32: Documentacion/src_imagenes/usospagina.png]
Usage Pages


Ahora hay que asignar el número de botones, este lo encontramos en la pagina de botones

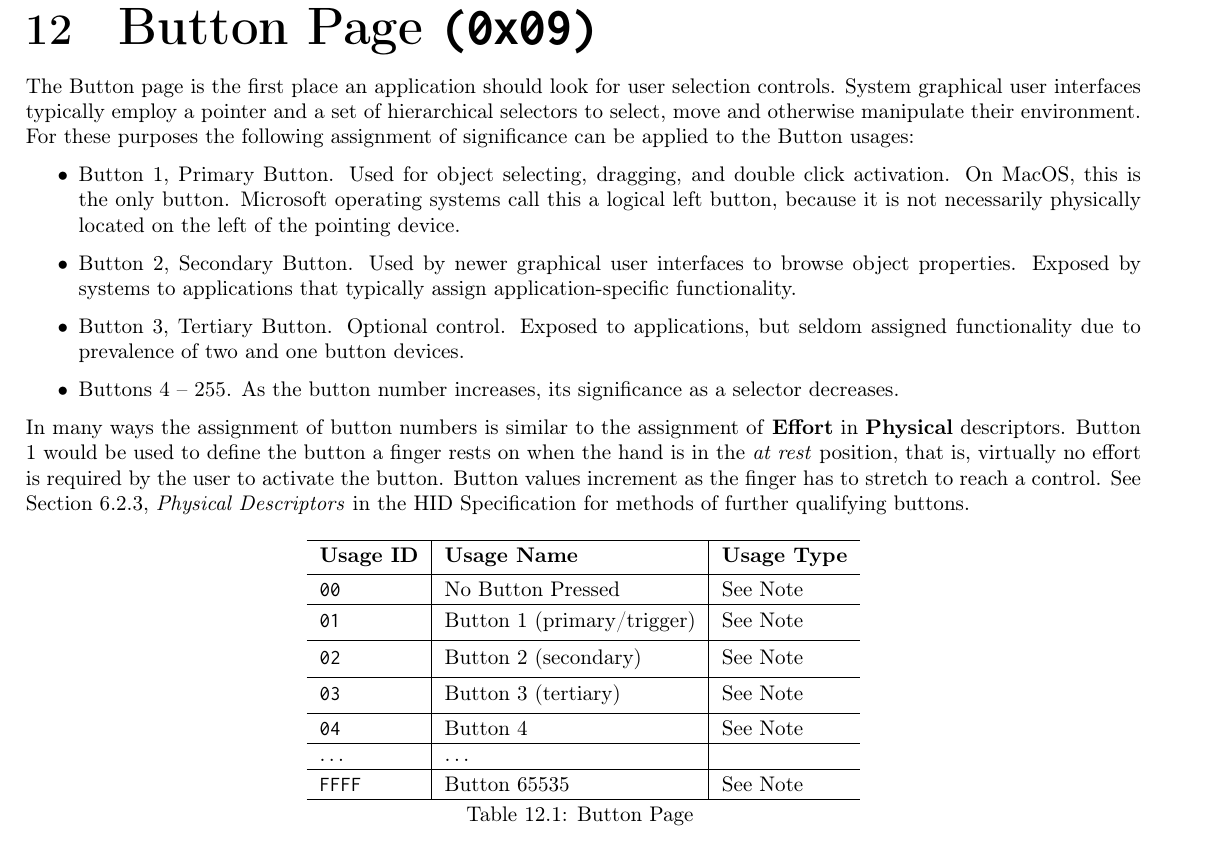
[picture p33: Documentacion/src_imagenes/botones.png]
botones


Como se observa podemos definir un rango muy grande de botones para usar, pero en este caso solo en necesario 7 botones, para este primer prototipo

Para definir los Ejes, estos los podemos encontrar en la "Generic Desktop Page" como X,Y,Z,Rx,Ry,Rz

Te recomiendo que veas estos 2 Documentos para que logres enteder mas en profunidad el porque de los valores ya que no abarque todos los temas, aunque puede que en 
futuro los agrege aquí

[Device Class Definition for Human Interface Devices (HID) Version1.11](https://www.usb.org/sites/default/files/hid1_11.pdf)
[HID Usage Tables FOR Universal Serial Bus (USB)](https://usb.org/sites/default/files/hut1_3_0.pdf)

Ya con los cambios realizados nos queda el siguiente dispositivo y se muestra de la siguiente forma en jstest-gtk

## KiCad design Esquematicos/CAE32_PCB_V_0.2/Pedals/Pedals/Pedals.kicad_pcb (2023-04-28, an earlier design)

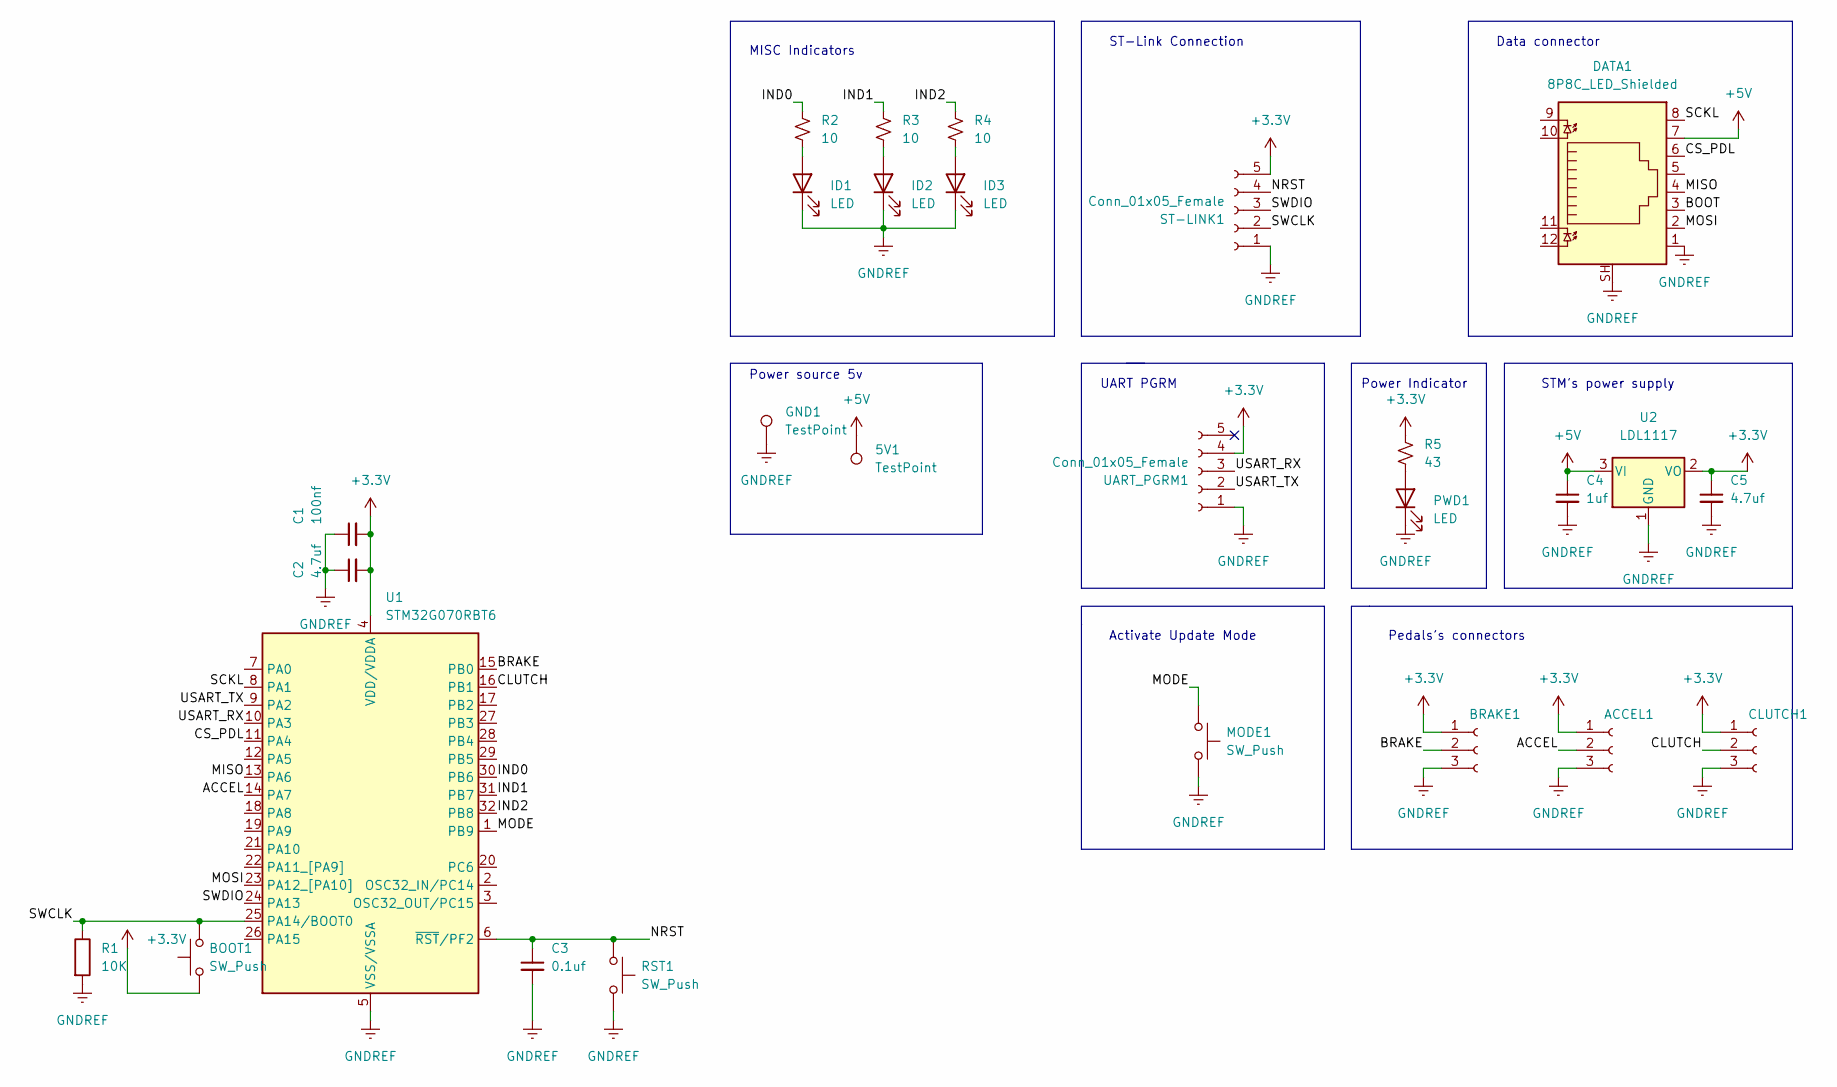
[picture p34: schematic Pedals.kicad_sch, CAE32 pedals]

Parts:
5V1: TestPoint; TestPoint_Pad_D3.0mm
ACCEL1: Conn_01x03_Female; JST_EH_B3B-EH-A_1x03_P2.50mm_Vertical
BOOT1: SW_Push; Panasonic_EVQPUM_EVQPUD
BRAKE1: Conn_01x03_Female; JST_EH_B3B-EH-A_1x03_P2.50mm_Vertical
C1: 100nf; C_0805_2012Metric_Pad1.18x1.45mm_HandSolder
C2, C5: 4.7uf; C_0805_2012Metric_Pad1.18x1.45mm_HandSolder
C3: 0.1uf; C_0805_2012Metric_Pad1.18x1.45mm_HandSolder
C4: 1uf; C_0805_2012Metric_Pad1.18x1.45mm_HandSolder
CLUTCH1: Conn_01x03_Female; JST_EH_B3B-EH-A_1x03_P2.50mm_Vertical
DATA1: 8P8C_LED_Shielded; RJ45_Amphenol_RJHSE538X
GND1: TestPoint; TestPoint_Pad_D3.0mm
ID1, ID2, ID3: LED; LED_0805_2012Metric_Pad1.15x1.40mm_HandSolder
MODE1: SW_Push; SW_Push_1P1T_NO_6x6mm_H9.5mm
PWD1: LED; LED_0805_2012Metric_Pad1.15x1.40mm_HandSolder
R1: 10K; R_0805_2012Metric_Pad1.20x1.40mm_HandSolder
R2, R3, R4: 10; R_0805_2012Metric_Pad1.20x1.40mm_HandSolder
R5: 43; R_0805_2012Metric_Pad1.20x1.40mm_HandSolder
RST1: SW_Push; Panasonic_EVQPUM_EVQPUD
ST-LINK1: Conn_01x05_Female; PinHeader_1x05_P2.54mm_Vertical
U1: STM32G070RBT6; LQFP-32_7x7mm_P0.8mm
U2: LDL1117; SOT-223-3_TabPin2
UART_PGRM1: Conn_01x05_Female; PinHeader_1x05_P2.54mm_Vertical

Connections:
+3.3V: ACCEL1.1, BOOT1.1, BRAKE1.1, C1.2, C2.2, C5.1, CLUTCH1.1, R5.1, ST-LINK1.5, U1.4 (VDD/VDDA), U2.2 (VO), UART_PGRM1.4
+5V: 5V1.1, C4.1, DATA1.7, U2.3 (VI)
/ACCEL: ACCEL1.2, U1.14 (PA7)
/BOOT: DATA1.3
/BRAKE: BRAKE1.2, U1.15 (PB0)
/CLUTCH: CLUTCH1.2, U1.16 (PB1)
/CS_PDL: DATA1.6, U1.11 (PA4)
/IND0: R2.1, U1.30 (PB6)
/IND1: R3.1, U1.31 (PB7)
/IND2: R4.1, U1.32 (PB8)
/MISO: DATA1.4, U1.13 (PA6)
/MODE: MODE1.1, U1.1 (PB9)
/MOSI: DATA1.2, U1.23 (PA12_[PA10])
/NRST: C3.1, RST1.1, ST-LINK1.4, U1.6 (~RST/PF2)
/SCKL: DATA1.8, U1.8 (PA1)
/SWCLK: BOOT1.2, R1.1, ST-LINK1.2, U1.25 (PA14/BOOT0)
/SWDIO: ST-LINK1.3, U1.24 (PA13)
/USART_RX: U1.10 (PA3), UART_PGRM1.3
/USART_TX: U1.9 (PA2), UART_PGRM1.2
GNDREF: ACCEL1.3, BRAKE1.3, C1.1, C2.1, C3.2, C4.2, C5.2, CLUTCH1.3, DATA1.1, DATA1.SH, GND1.1, ID1.1 (K), ID2.1 (K), ID3.1 (K), MODE1.2, PWD1.1 (K), R1.2, RST1.2, ST-LINK1.1, U1.5 (VSS/VSSA), U2.1 (GND), UART_PGRM1.1
unnamed: ID1.2 (A), R2.2
unnamed: ID2.2 (A), R3.2
unnamed: ID3.2 (A), R4.2
unnamed: PWD1.2 (A), R5.2

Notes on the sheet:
ST-Link Connection
STM's power supply
Pedals's connectors
Activate Update Mode
Power source 5v
MISC Indicators
Power Indicator
UART PGRM
Data connector

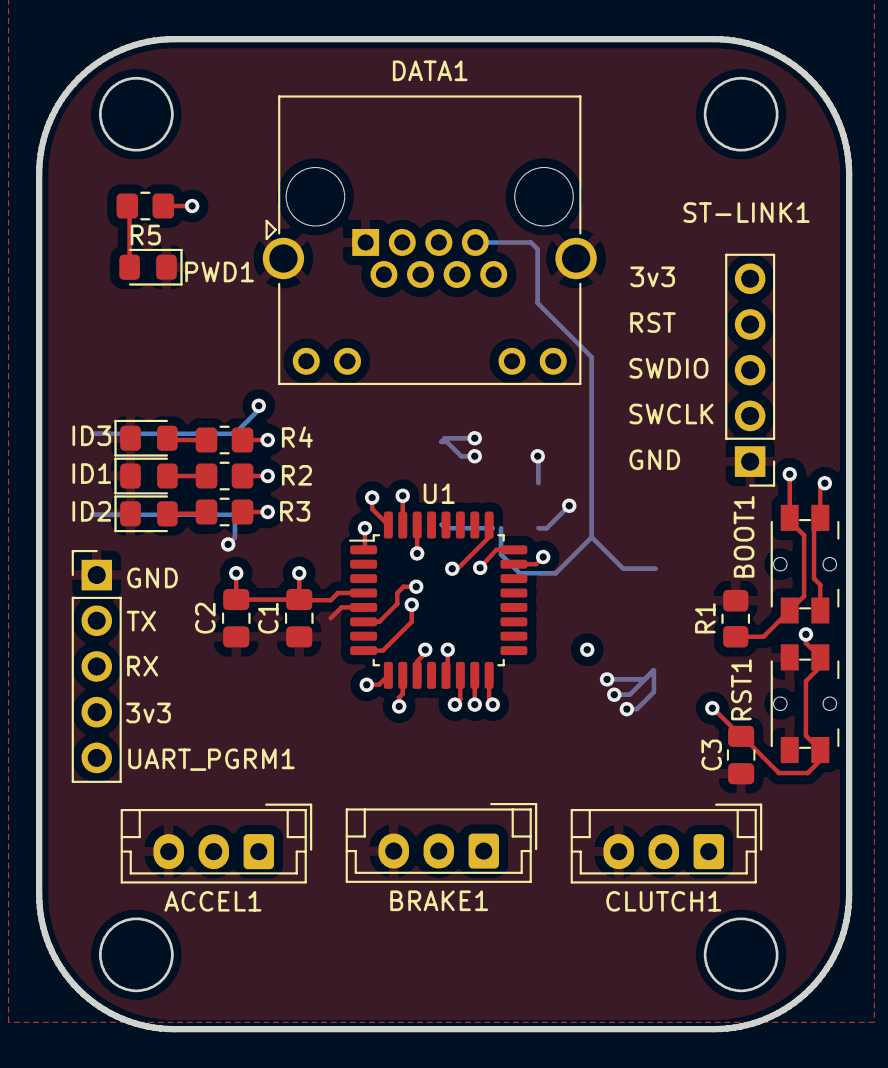
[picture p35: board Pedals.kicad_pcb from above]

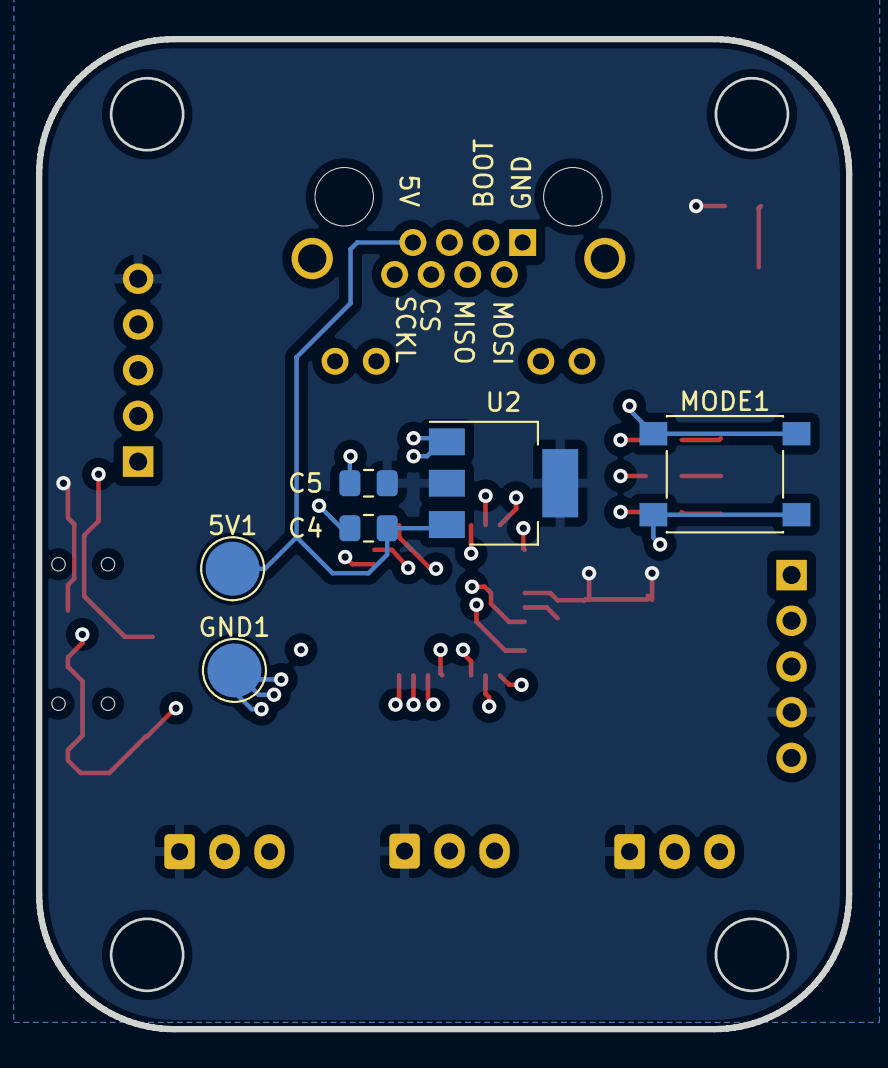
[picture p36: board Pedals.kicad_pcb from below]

Board: 4 copper layers, 45.0 x 55.0 mm, 27 parts (6 on the bottom side), 23 nets.

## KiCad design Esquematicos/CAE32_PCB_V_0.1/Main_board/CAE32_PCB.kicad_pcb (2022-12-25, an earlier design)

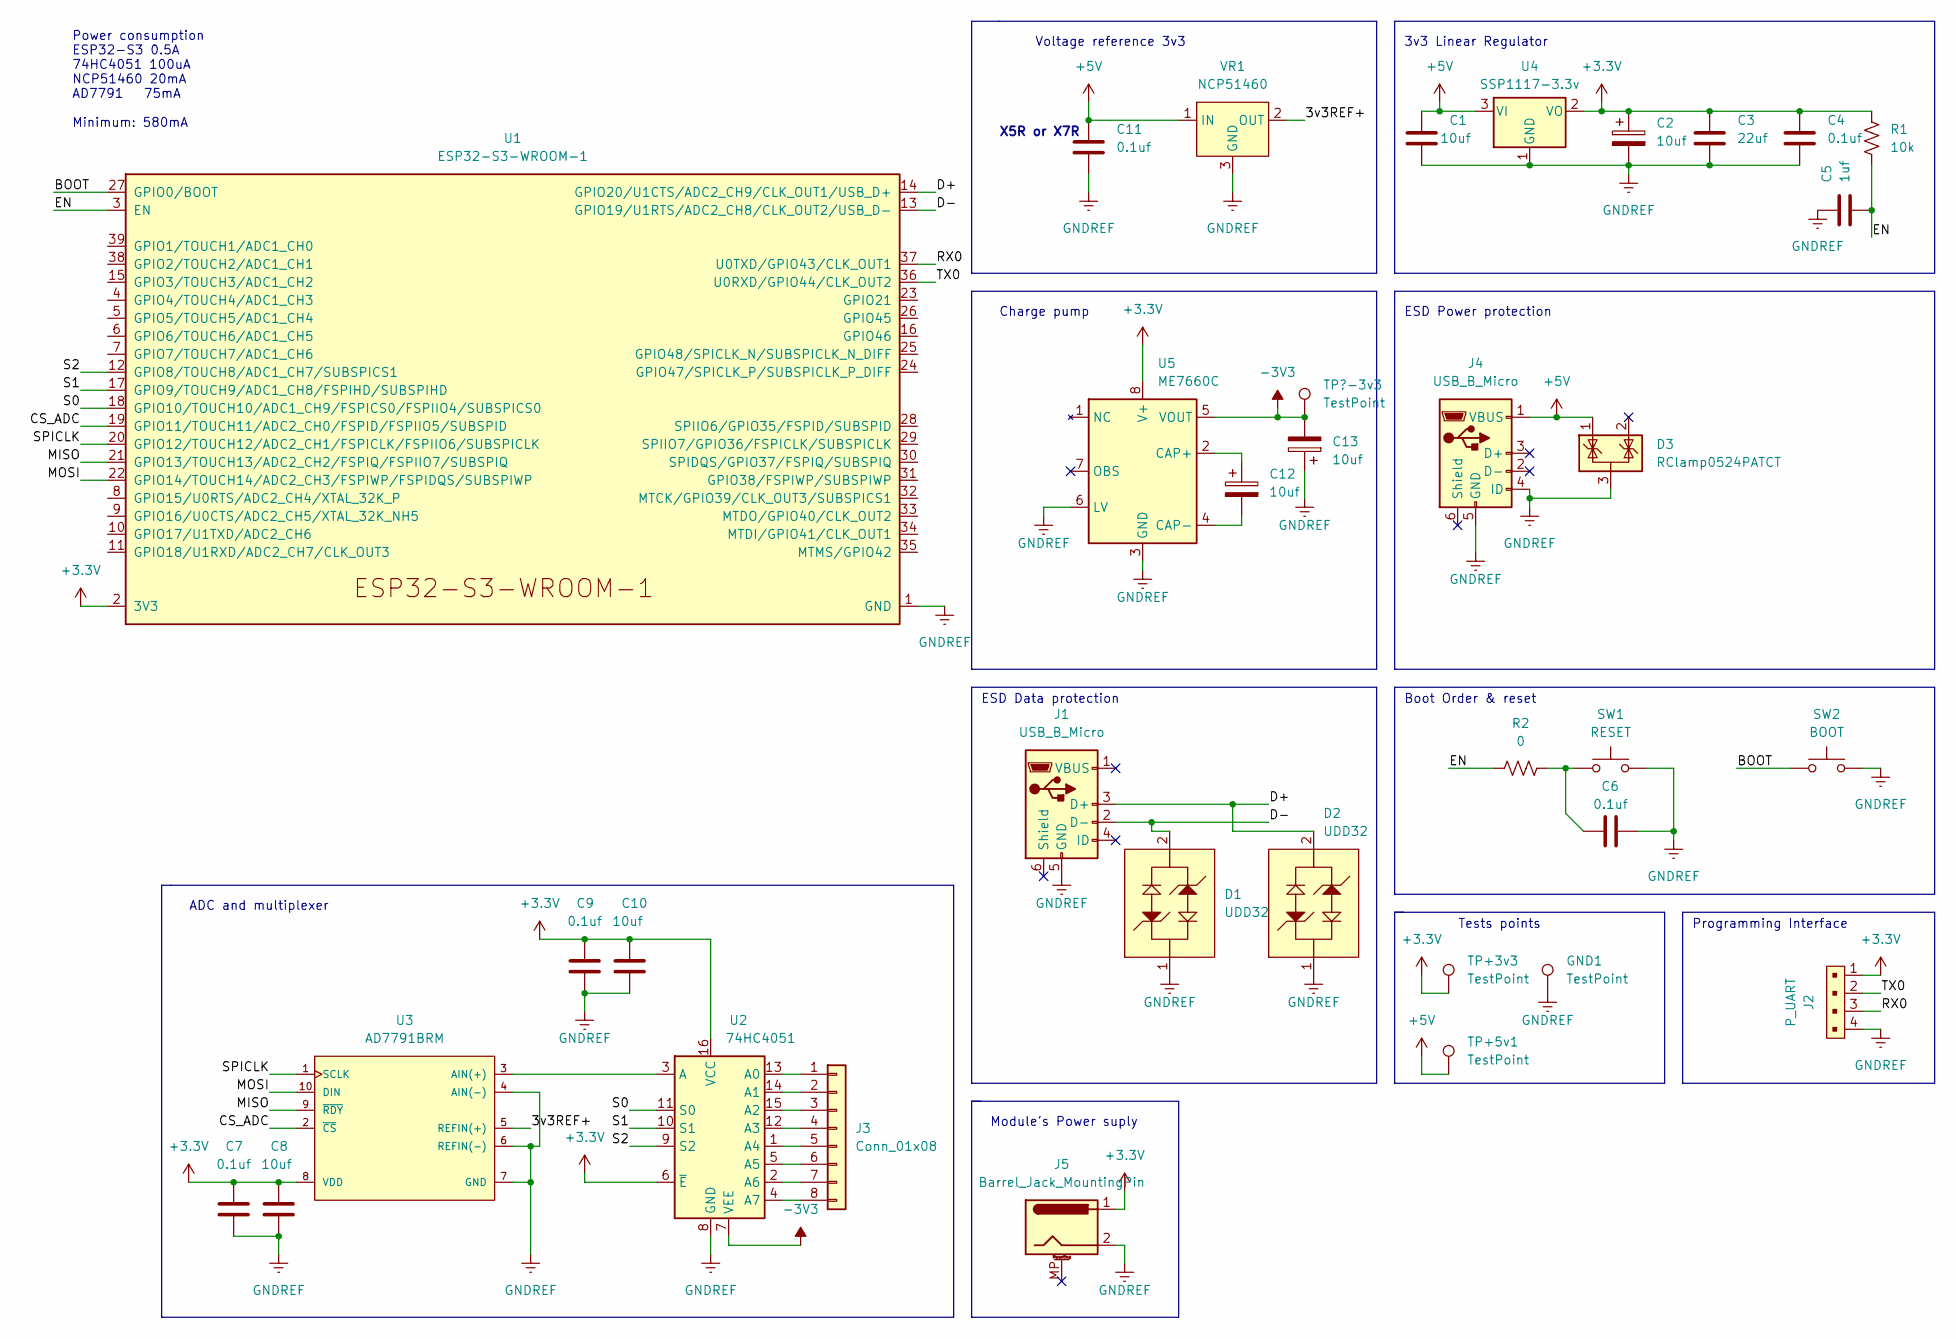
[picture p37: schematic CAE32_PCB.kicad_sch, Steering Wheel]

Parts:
C1, C8, C10, C12, C13: 10uf; C_0805_2012Metric
C2: 10uf; D_0805_2012Metric
C3: 22uf; C_0805_2012Metric
C4, C6, C7, C9, C11: 0.1uf; C_0805_2012Metric
C5: 1uf; C_0805_2012Metric
D1, D2: UDD32
D3: RClamp0524PATCT; SOT-23
GND1: TestPoint; TestPoint_Pad_D2.5mm
J1, J4: USB_B_Micro; USB_Micro-B_Amphenol_10118194_Horizontal
J2: P_UART; PinSocket_1x04_P2.54mm_Vertical; MPN 0022232041; Digi-Key_PN WM4202-ND
J3: Conn_01x08; PinSocket_1x08_P2.54mm_Vertical
J5: Barrel_Jack_MountingPin; BarrelJack_Wuerth_6941xx301002
R1: 10k; R_0805_2012Metric
R2: 0; R_0805_2012Metric
SW1: RESET; SW_SPST_PTS810
SW2: BOOT; SW_SPST_PTS810
TP+3v3, TP+5v1: TestPoint; TestPoint_Pad_D2.5mm
TP?-3v3: TestPoint; TestPoint_Pad_D2.5mm
U1: ESP32-S3-WROOM-1
U2: 74HC4051; SOIC-16W_5.3x10.2mm_P1.27mm
U3: AD7791BRM; SSOP-10_3.9x4.9mm_P1.00mm
U4: SSP1117-3.3v; SOT-223-3_TabPin2
U5: ME7660C; SSOP-8_3.9x5.05mm_P1.27mm; LCSC C88402
VR1: NCP51460; SOT-23; MPN REF3030AIDBZR; Digi-Key_PN 296-26323-1-ND

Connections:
+3.3V: C2.1, C3.1, C4.1, C7.1, C8.1, C9.1, C10.1, J2.1, J5.1, R1.1, TP+3v3.1, U1.2 (3V3), U2.6 (~E), U2.16 (VCC), U3.8 (VDD), U4.2 (VO), U5.8 (V+)
+5V: C1.1, C11.1, D3.1 (K), J4.1 (VBUS), TP+5v1.1, U4.3 (VI), VR1.1 (IN)
-3V3: C13.2, TP?-3v3.1, U2.7 (VEE), U5.5 (VOUT)
/3v3REF+: U3.5 (REFIN(+)), VR1.2 (OUT)
/BOOT: SW2.1, U1.27 (GPIO0/BOOT)
/CS_ADC: U1.19 (GPIO11/TOUCH11/ADC2_CH0/FSPID/FSPIIO5/S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), U3.2 (~CS)
/D+: D2.2, J1.3 (D+), U1.14 (GPIO20/U1CTS/ADC2_CH9/CLK_OUT1/USB_D+)
/D-: D1.2, J1.2 (D-), U1.13 (GPIO19/U1RTS/ADC2_CH8/CLK_OUT2/USB_D-)
/EN: C5.2, R1.2, R2.1, U1.3 (EN)
/MISO: U1.21 (GPIO13/TOUCH13/ADC2_CH2/FSPIQ/FSPIIO7/S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), U3.9 (~RDY)
/MOSI: U1.22 (GPIO14/TOUCH14/ADC2_CH3/FSPIWP/FSPIDQS/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), U3.10 (DIN)
/RX0: J2.3, U1.37 (U0TXD/GPIO43/CLK_OUT1)
/S0: U1.18 (GPIO10/TOUCH10/ADC1_CH9/FSPICS0/FSPIIO4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), U2.11 (S0)
/S1: U1.17 (GPIO9/TOUCH9/ADC1_CH8/FSPIHD/SUBSPIHD), U2.10 (S1)
/S2: U1.12 (GPIO8/TOUCH8/ADC1_CH7/SUBSPICS1), U2.9 (S2)
/SPICLK: U1.20 (GPIO12/TOUCH12/ADC2_CH1/FSPICLK/FSPIIO6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), U3.1 (SCLK)
/TX0: J2.2, U1.36 (U0RXD/GPIO44/CLK_OUT2)
GNDREF: C1.2, C2.2, C3.2, C4.2, C5.1, C6.2, C7.2, C8.2, C9.2, C10.2, C11.2, C13.1, D1.1, D2.1, D3.3 (A), GND1.1, J1.5 (GND), J2.4, J4.4 (ID), J4.5 (GND), J5.2, SW1.2, SW2.2, U1.1 (GND), U1.40 (GND), U1.41 (GND), U2.8 (GND), U3.4 (AIN(-)), U3.6 (REFIN(-)), U3.7 (GND), U4.1 (GND), U5.3 (GND), U5.6 (LV), VR1.3 (GND)
unnamed: C6.1, R2.2, SW1.1
unnamed: C12.1, U5.2 (CAP+)
unnamed: C12.2, U5.4 (CAP-)
unnamed: J3.1, U2.13 (A0)
unnamed: J3.2, U2.14 (A1)
unnamed: J3.3, U2.15 (A2)
unnamed: J3.4, U2.12 (A3)
unnamed: J3.5, U2.1 (A4)
unnamed: J3.6, U2.5 (A5)
unnamed: J3.7, U2.2 (A6)
unnamed: J3.8, U2.4 (A7)
unnamed: U2.3 (A), U3.3 (AIN(+))

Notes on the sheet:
Voltage reference 3v3
ADC and multiplexer
ESD Data protection
ESD Power protection
Charge pump
Module's Power suply
Programming Interface
Power consumption ESP32-S3 0.5A 74HC4051 100uA NCP51460 20mA AD7791 75mA Minimum: 580mA
Boot Order & reset
3v3 Linear Regulator
Tests points
X5R or X7R

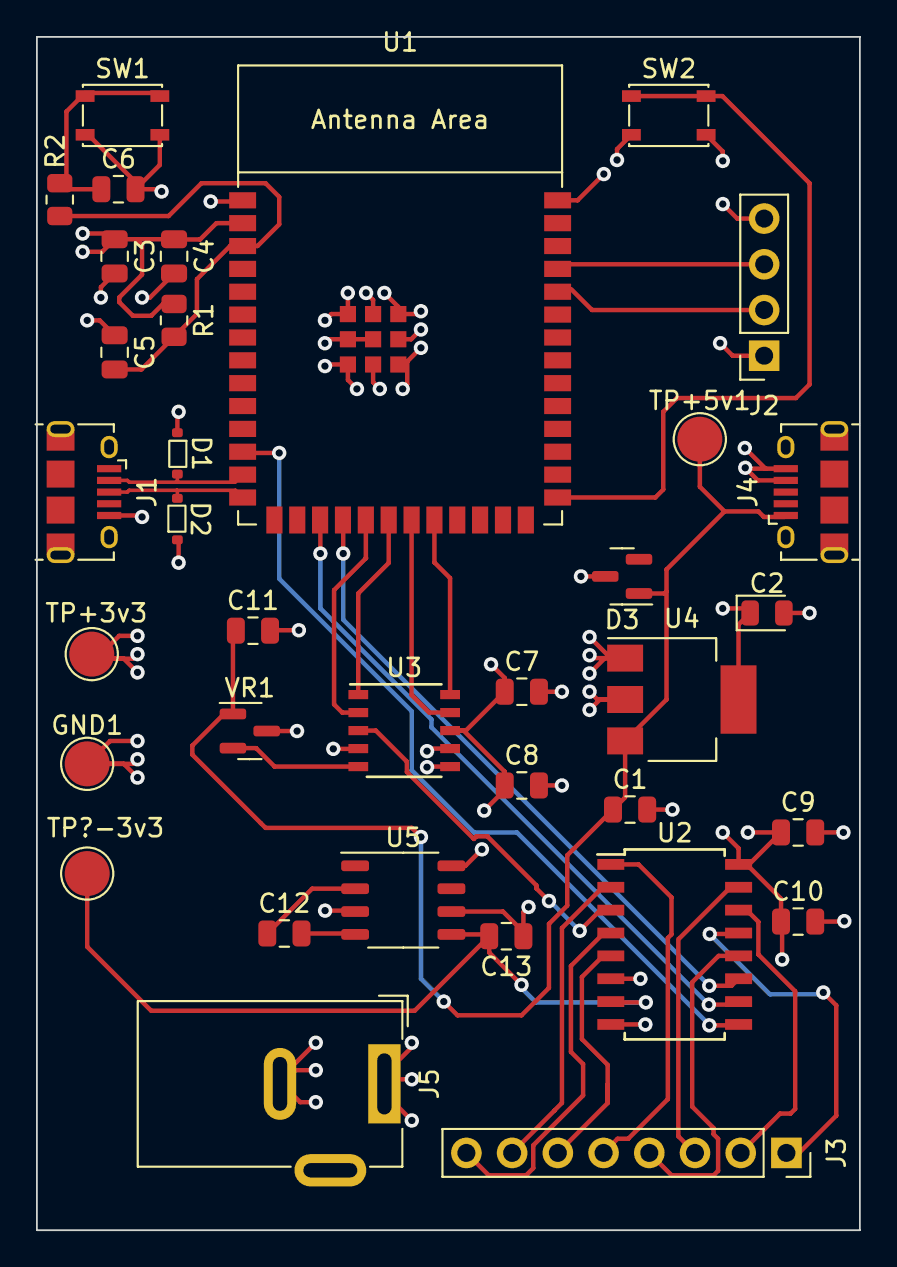
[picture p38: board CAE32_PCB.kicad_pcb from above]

Board: 4 copper layers, 45.7 x 66.3 mm, 35 parts (0 on the bottom side), 30 nets.

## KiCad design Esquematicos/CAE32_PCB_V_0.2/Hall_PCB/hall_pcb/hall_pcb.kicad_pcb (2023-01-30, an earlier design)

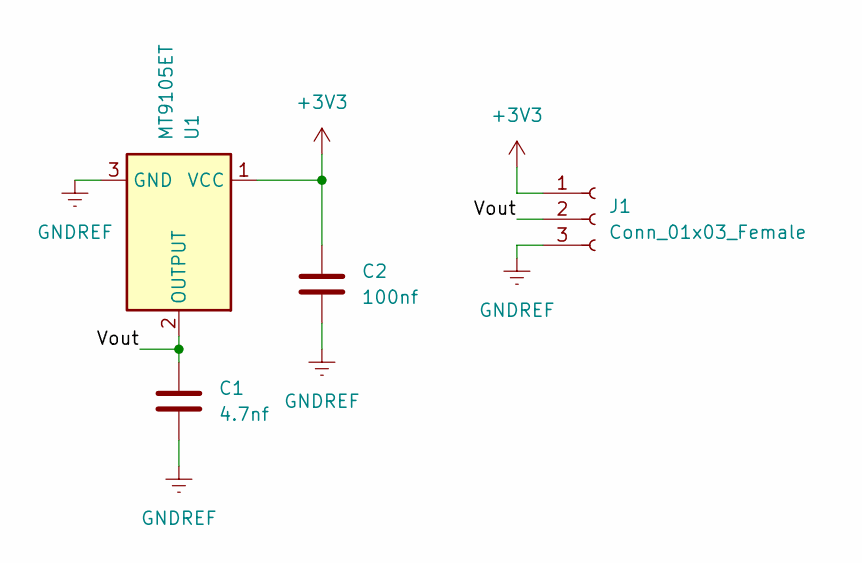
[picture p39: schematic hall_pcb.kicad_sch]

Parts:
C1: 4.7nf; C_0805_2012Metric_Pad1.18x1.45mm_HandSolder
C2: 100nf; C_0805_2012Metric_Pad1.18x1.45mm_HandSolder
J1: Conn_01x03_Female; JST_EH_B3B-EH-A_1x03_P2.50mm_Vertical
U1: MT9105ET; SOT-23

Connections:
+3V3: C2.1, J1.1, U1.1 (VCC)
/Vout: C1.1, J1.2, U1.2 (OUTPUT)
GNDREF: C1.2, C2.2, J1.3, U1.3 (GND)

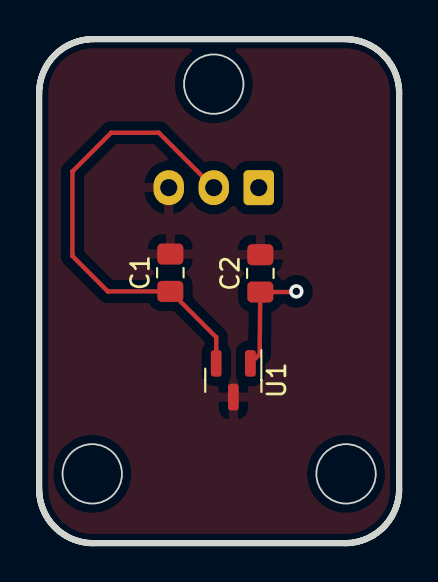
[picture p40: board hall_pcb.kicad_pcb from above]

Board: 2 copper layers, 20.0 x 28.0 mm, 4 parts (1 on the bottom side), 3 nets.

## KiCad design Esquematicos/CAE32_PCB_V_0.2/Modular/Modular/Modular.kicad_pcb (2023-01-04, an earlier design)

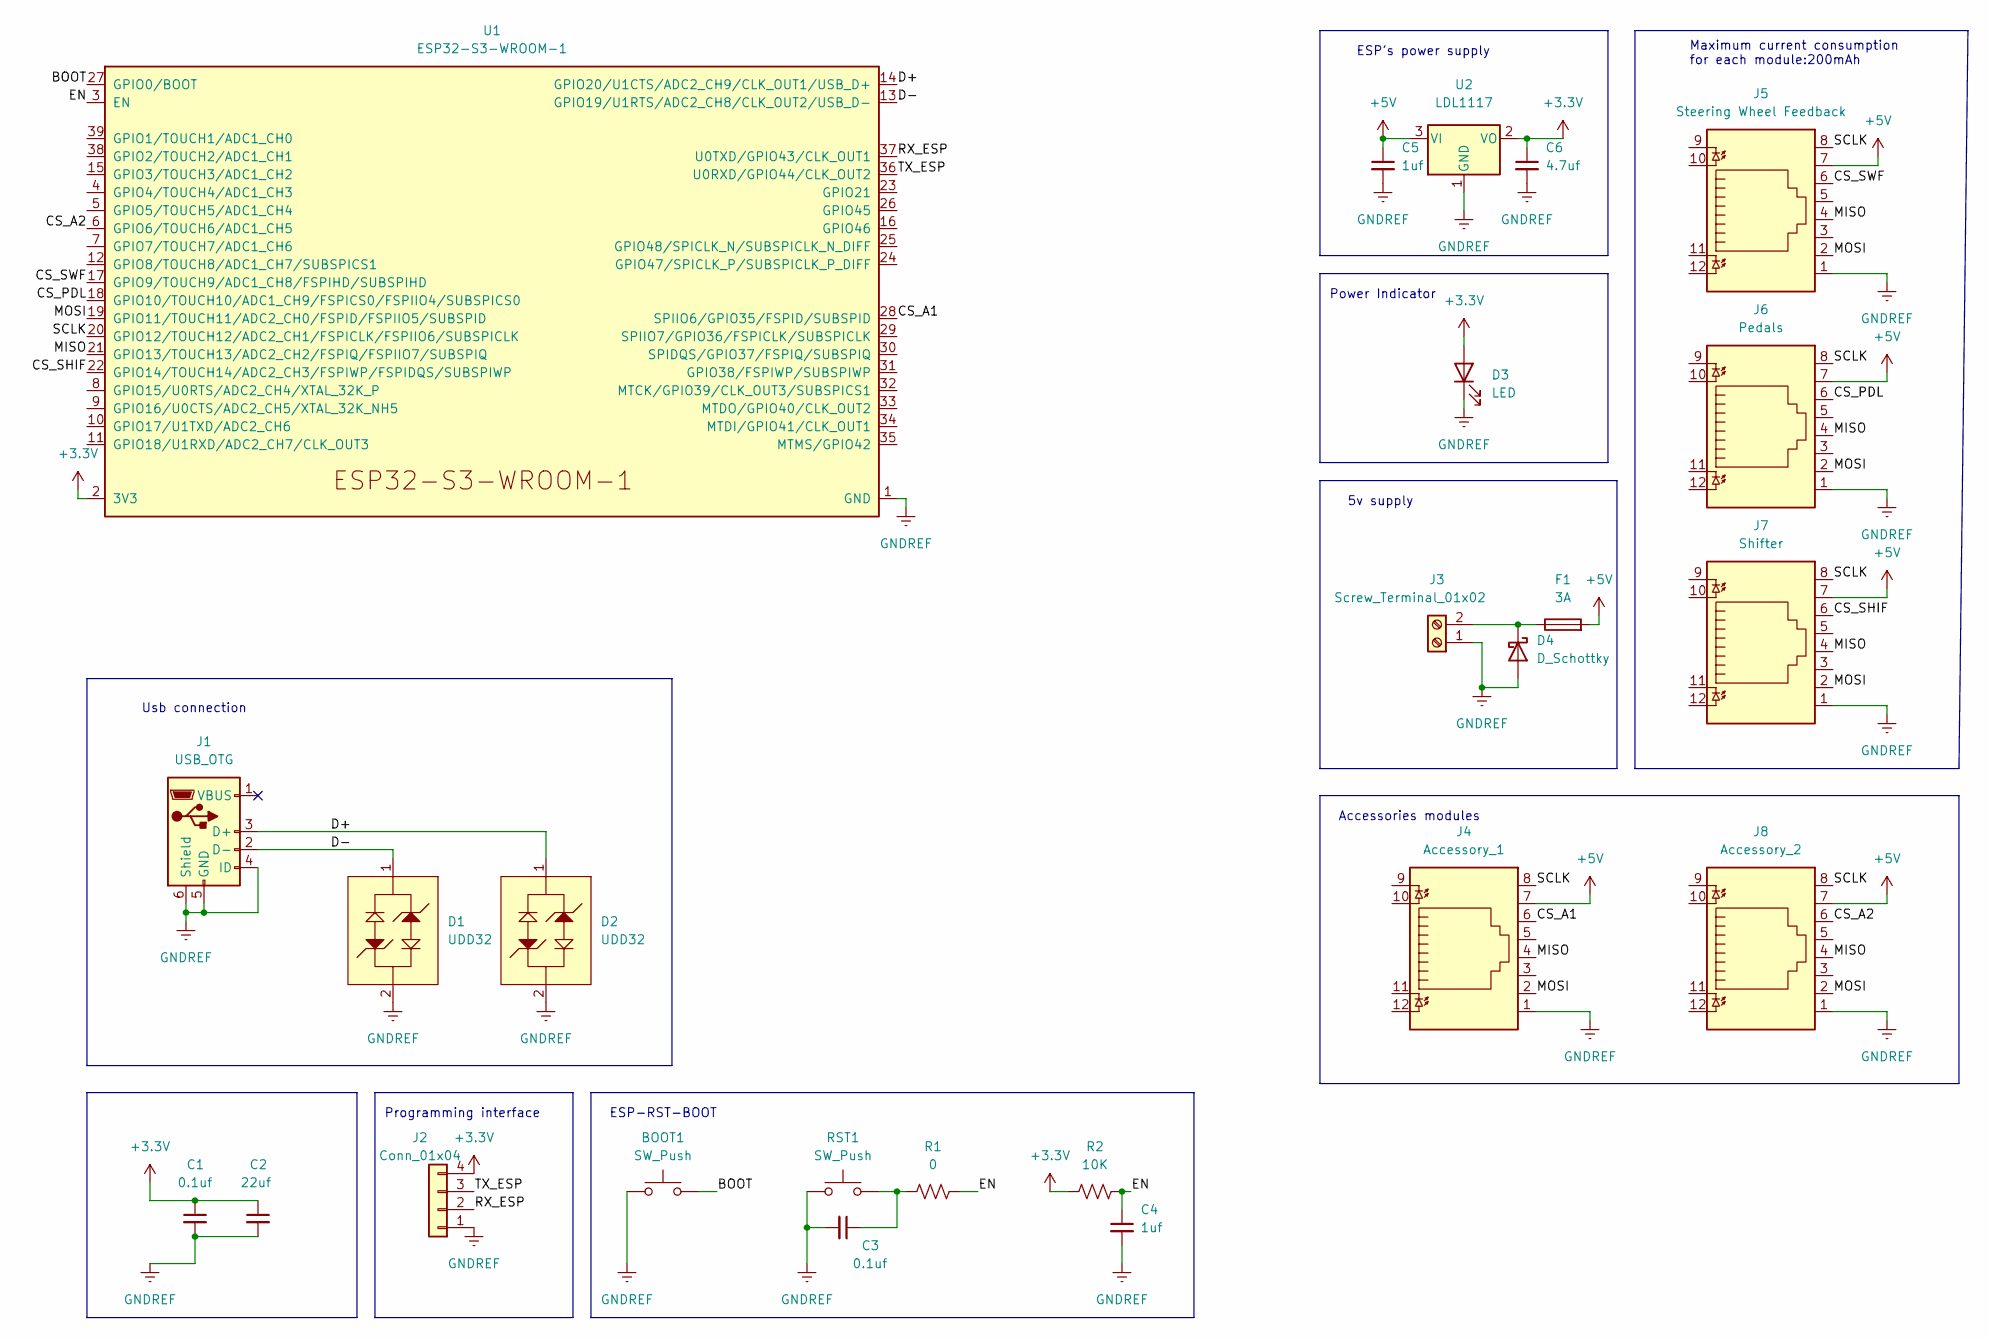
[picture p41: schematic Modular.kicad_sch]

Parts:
BOOT1: SW_Push; SW_Push_1P1T_NO_CK_KSC6xxJ
C1, C3: 0.1uf; C_0805_2012Metric_Pad1.18x1.45mm_HandSolder
C2: 22uf; C_0805_2012Metric_Pad1.18x1.45mm_HandSolder
C4, C5: 1uf; C_0805_2012Metric_Pad1.18x1.45mm_HandSolder
C6: 4.7uf; C_0805_2012Metric_Pad1.18x1.45mm_HandSolder
D1, D2: UDD32
D3: LED; LED_0805_2012Metric_Pad1.15x1.40mm_HandSolder
D4: D_Schottky; D_SMA_Handsoldering
F1: 3A; Fuse_1812_4532Metric_Pad1.30x3.40mm_HandSolder
J1: USB_OTG; USB_Micro-B_Amphenol_10104110_Horizontal
J2: Conn_01x04; PinHeader_1x04_P2.54mm_Vertical
J3: Screw_Terminal_01x02; TerminalBlock_bornier-2_P5.08mm
J4: Accessory_1; RJ45_Amphenol_RJHSE538X
J5: Steering Wheel Feedback; RJ45_Amphenol_RJHSE538X
J6: Pedals; RJ45_Amphenol_RJHSE538X
J7: Shifter; RJ45_Amphenol_RJHSE538X
J8: Accessory_2; RJ45_Amphenol_RJHSE538X
R1: 0; R_0805_2012Metric_Pad1.20x1.40mm_HandSolder
R2: 10K; R_0805_2012Metric_Pad1.20x1.40mm_HandSolder
RST1: SW_Push; SW_Push_1P1T_NO_CK_KSC6xxJ
U1: ESP32-S3-WROOM-1
U2: LDL1117; SOT-223-3_TabPin2

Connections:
+3.3V: C1.1, C2.1, C6.1, D3.2 (A), J2.4, R2.1, U1.2 (3V3), U2.2 (VO)
+5V: C5.1, F1.2, J4.7, J5.7, J6.7, J7.7, J8.7, U2.3 (VI)
/BOOT: BOOT1.2, U1.27 (GPIO0/BOOT)
/CS_A1: J4.6, U1.28 (SPIIO6/GPIO35/FSPID/SUBSPID)
/CS_A2: J8.6, U1.6 (GPIO6/TOUCH6/ADC1_CH5)
/CS_PDL: J6.6, U1.18 (GPIO10/TOUCH10/ADC1_CH9/FSPICS0/FSPIIO4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)
/CS_SHIF: J7.6, U1.22 (GPIO14/TOUCH14/ADC2_CH3/FSPIWP/FSPIDQS/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)
/CS_SWF: J5.6, U1.17 (GPIO9/TOUCH9/ADC1_CH8/FSPIHD/SUBSPIHD)
/D+: D2.1, J1.3 (D+), U1.14 (GPIO20/U1CTS/ADC2_CH9/CLK_OUT1/USB_D+)
/D-: D1.1, J1.2 (D-), U1.13 (GPIO19/U1RTS/ADC2_CH8/CLK_OUT2/USB_D-)
/EN: C4.1, R1.2, R2.2, U1.3 (EN)
/MISO: J4.4, J5.4, J6.4, J7.4, J8.4, U1.21 (GPIO13/TOUCH13/ADC2_CH2/FSPIQ/FSPIIO7/S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)
/MOSI: J4.2, J5.2, J6.2, J7.2, J8.2, U1.19 (GPIO11/TOUCH11/ADC2_CH0/FSPID/FSPIIO5/S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)
/RX_ESP: J2.2, U1.37 (U0TXD/GPIO43/CLK_OUT1)
/SCLK: J4.8, J5.8, J6.8, J7.8, J8.8, U1.20 (GPIO12/TOUCH12/ADC2_CH1/FSPICLK/FSPIIO6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)
/TX_ESP: J2.3, U1.36 (U0RXD/GPIO44/CLK_OUT2)
GNDREF: BOOT1.1, C1.2, C2.2, C3.2, C4.2, C5.2, C6.2, D1.2, D2.2, D3.1 (K), D4.2 (A), J1.4 (ID), J1.5 (GND), J1.6 (Shield), J2.1, J3.1, J4.1, J5.1, J6.1, J7.1, J8.1, RST1.1, U1.1 (GND), U1.40 (GND), U1.41 (GND), U2.1 (GND)
unnamed: C3.1, R1.1, RST1.2
unnamed: D4.1 (K), F1.1, J3.2

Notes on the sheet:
Maximum current consumption for each module:200mAh
Power Indicator
Usb connection
Accessories modules
5v supply
Programming interface
ESP's power supply
ESP-RST-BOOT

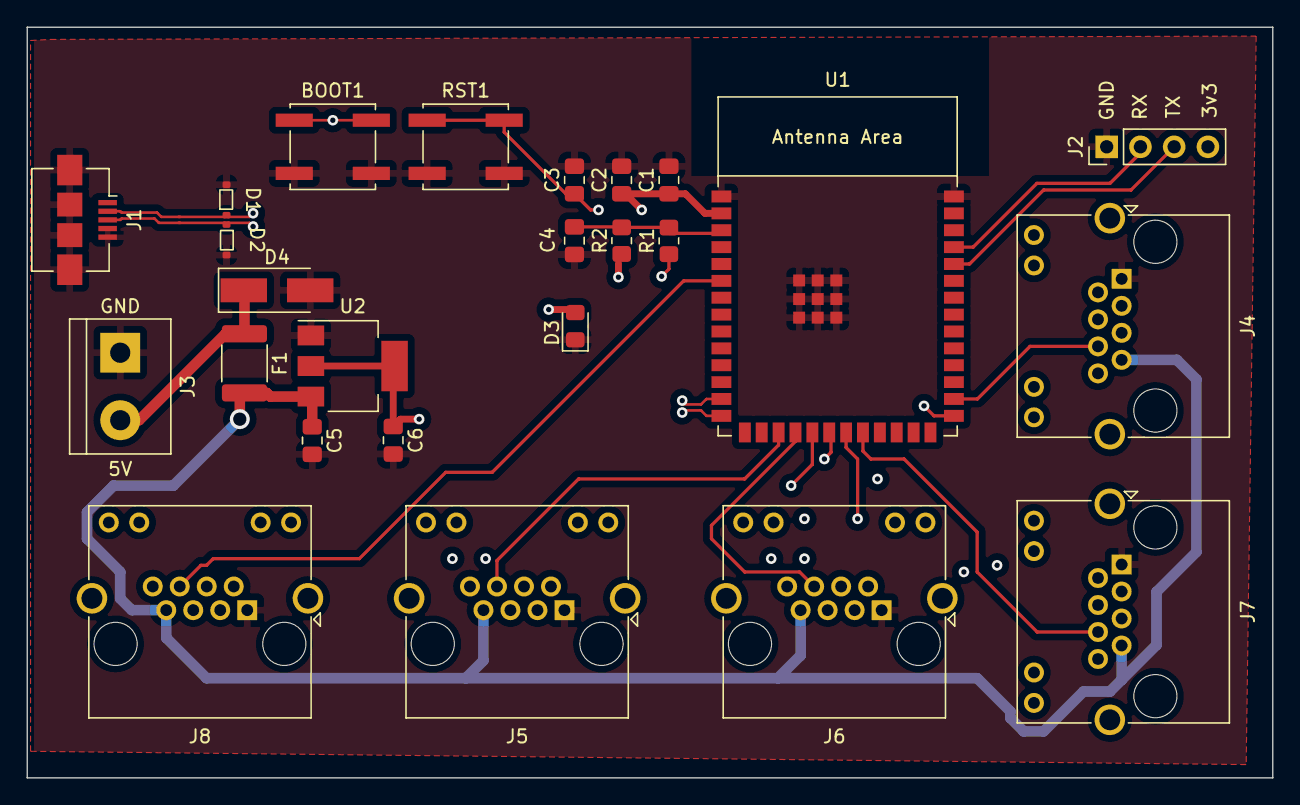
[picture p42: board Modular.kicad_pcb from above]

Board: 4 copper layers, 93.8 x 56.5 mm, 25 parts (0 on the bottom side), 19 nets.

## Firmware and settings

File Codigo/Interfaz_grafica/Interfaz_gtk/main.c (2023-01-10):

#include "cae32_app.h"
// #include "device.h"
// #include "objectsGtk.h"
#include <gtk/gtk.h>

/*static void activate(GtkApplication *app, gpointer userdata) {

  Device CAE32;
  Device *p_CAE32 = g_malloc(sizeof(Device));
  p_CAE32 = &CAE32;
  ObjectsUI obj;
  GError *error = NULL;
  GtkBuilder *constructor = gtk_builder_new();
  if (gtk_builder_add_from_file(constructor, "../gladeFiles/UI1.glade", &error) == 0) {
    g_printerr("Error no se encontro el archivo :%s \n", error->message);
    g_clear_error(&error);
    //  return 1;
  }
  GObject *window = gtk_builder_get_object(constructor, "ventana");
  gtk_window_set_application(GTK_WINDOW(window), app);
  initObjects(constructor, &obj);
  signalsConnection(&obj);

  g_signal_connect(obj.reconectar, "clicked", G_CALLBACK(searchDevice), (gpointer)p_CAE32);
  gtk_widget_show(GTK_WIDGET(window));
  g_object_unref(constructor);
}*/

int main(int argc, char *argv[]) {
  GtkApplication *app;
  app = cae32_app_new();

  return g_application_run(G_APPLICATION(app), argc, argv);
}

/*
GtkApplication *app = gtk_application_new("org.gtk.example", G_APPLICATION_FLAGS_NONE);
  g_signal_connect(app, "activate", G_CALLBACK(activate), NULL);
  int status = g_application_run(G_APPLICATION(app), argc, argv);
  g_object_unref(app);

  return status;
*/

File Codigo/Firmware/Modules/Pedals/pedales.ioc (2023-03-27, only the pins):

Mcu.UserName=STM32G070KBTx
PA1.Signal=SPI1_SCK
PA2.Signal=SPI1_MOSI
PA4.Signal=SPI1_NSS
PA6.Signal=SPI1_MISO
PA7.Signal=ADC1_IN7
PB0.Signal=ADC1_IN8
PB1.Signal=ADC1_IN9
PB6.Signal=GPIO_Output
PB7.Signal=GPIO_Output
PB8.Signal=GPIO_Output

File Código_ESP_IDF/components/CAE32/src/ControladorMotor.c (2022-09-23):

#include "stdbool.h"
#include "driver/mcpwm.h"
#include "driver/adc.h" 
#include "freertos/FreeRTOS.h"
#include "freertos/task.h"
#include "ConfADC.h"
#include "driver/gpio.h"


//#define ADC_CHANNEL_ANGULO ADC1_CHANNEL_7



void ConfPinEntrada (){
gpio_config_t BotonRutina={
    .mode=GPIO_MODE_INPUT,
    .pull_up_en=GPIO_PULLUP_ENABLE,
    .pin_bit_mask=GPIO_NUM_13,
};
gpio_config(&BotonRutina);
}

void FrenarMotor(){
    mcpwm_set_signal_low(MCPWM_UNIT_0, MCPWM_TIMER_0, MCPWM_OPR_A);
    mcpwm_set_signal_low(MCPWM_UNIT_0, MCPWM_TIMER_0, MCPWM_OPR_B);
    vTaskDelay(100/ portTICK_PERIOD_MS);
}

void MoverSentidoHorario(float cicloDeTrabajo){
    mcpwm_set_signal_low(MCPWM_UNIT_0, MCPWM_TIMER_0, MCPWM_OPR_B);
    mcpwm_set_duty(MCPWM_UNIT_0, MCPWM_TIMER_0, MCPWM_OPR_A, cicloDeTrabajo);
    mcpwm_set_duty_type(MCPWM_UNIT_0, MCPWM_TIMER_0, MCPWM_OPR_A, MCPWM_DUTY_MODE_0); //call this each time, if operator was previously in low/high state
}

void MoverSentidoAntihorario(float cicloDeTrabajo){
    mcpwm_set_signal_low(MCPWM_UNIT_0, MCPWM_TIMER_0, MCPWM_OPR_A);
    mcpwm_set_duty(MCPWM_UNIT_0, MCPWM_TIMER_0, MCPWM_OPR_B, cicloDeTrabajo);
    mcpwm_set_duty_type(MCPWM_UNIT_0, MCPWM_TIMER_0, MCPWM_OPR_B, MCPWM_DUTY_MODE_0);  //call this each time, if operator was previously in low/high state
}

void MoverSentidoGiro(float cicloDeTrabajo, int sentidoDeGiro){
    int signal_low_opr=0;
    int duty_type_opr=0;
    switch (sentidoDeGiro)
    {
    case 1://Sentido horario
        signal_low_opr=1;
        duty_type_opr=0;
        break;
    case -1://Sentido antihorario
        signal_low_opr=0;
        duty_type_opr=1;

        break;
    default:
        break;
    }
    mcpwm_set_signal_low(MCPWM_UNIT_0, MCPWM_TIMER_0, signal_low_opr);
    mcpwm_set_duty(MCPWM_UNIT_0, MCPWM_TIMER_0, duty_type_opr, cicloDeTrabajo);
    mcpwm_set_duty_type(MCPWM_UNIT_0, MCPWM_TIMER_0, duty_type_opr, MCPWM_DUTY_MODE_0); //call this each time, if operator was previously in low/high state
    //vTaskDelay(500/ portTICK_PERIOD_MS);
}

/**
 * @brief Mueve el motor por un tiempo definido, además de elegir el sentido de giro y la potencia
 * 
 * @param milisegundos 
 * @param sentidoDeGiro true=Derecha(Sentido horario) false=Izquierda (Sentido antihorario) 
 * @param cicloDeTrabajo 
 */
void MoverMotorPorTiempo(int milisegundos,int sentidoDeGiro,float cicloDeTrabajo){
    MoverSentidoGiro(cicloDeTrabajo,sentidoDeGiro);
    vTaskDelay(milisegundos / portTICK_PERIOD_MS);
    FrenarMotor();

}
/**
 * @brief Mueve el indicador a los grados deseados
 * 
 * @param gradosDeseados 
 *
 * @param cicloDeTrabajo 
 * @return true 
 * @return false 
 */
bool MoverMotorAGrados(int gradosDeseados,float cicloDeTrabajo){ //Agregar la caracteristica de control PID
    if (gradosDeseados>270)
    {
        return false;
    }
   

    do
    {
      printf("/*LALO,%d,%d*/\n",VoltajeAGrados(),gradosDeseados);
      if (gradosDeseados>VoltajeAGrados()){
        //gira a la derecha
        MoverSentidoGiro(cicloDeTrabajo,-1);
      }
    else{
        //gira a la izquierda
     
        MoverSentidoGiro(cicloDeTrabajo,1);
    }
      vTaskDelay(110/ portTICK_PERIOD_MS);
      
    } while (VoltajeAGrados()!=gradosDeseados);
     FrenarMotor();
    return true;
}

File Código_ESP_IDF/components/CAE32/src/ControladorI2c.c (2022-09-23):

#include "driver/i2c.h"
#include "esp_err.h"
#include "freertos/task.h"
#include  "ControladorMotor.h"



/**
 *  Hacer algo con los define correspondientes al la inicialización ya que se encuentran duplicados en 2 archivos c
 *  Agregar punteros para las variables conocidas como dato 1 y 2
 *  Modificar la función de escritura ya que creo que inicia y cierra la comunicación para cado dato, en vez de enviar toda la trama y cerrar la comunicación
 *  crear una función varidica para enviar la trama de datos
 */












#define I2C_MASTER_SCL_IO           22      /*!< GPIO number used for I2C master clock */
#define I2C_MASTER_SDA_IO           21      /*!< GPIO number used for I2C master data  */
#define I2C_MASTER_NUM              0                          /*!< I2C master i2c port number, the number of i2c peripheral interfaces available will depend on the chip */
#define I2C_MASTER_FREQ_HZ          400000                     /*!< I2C master clock frequency */
#define I2C_MASTER_TX_BUF_DISABLE   0                          /*!< I2C master doesn't need buffer */
#define I2C_MASTER_RX_BUF_DISABLE   0                          /*!< I2C master doesn't need buffer */
#define I2C_MASTER_TIMEOUT_MS       1000


// Registros para la configuración y calibración del as5600-----------------------------------------------
#define ADDR 0x36
#define CONF_REG 0x08
#define RAW_ANGLE4b 0x0C
#define RAW_ANGLE8b 0x0D
#define ZPOS4b 0x01
#define ZPOS8b 0x02
#define MANG4b 0x05
#define MANG8b 0x06
#define MPOS4b 0x03
#define MPOS8b 0x04
// --------------------------------------------------------------------------------------------------------


// Variables para almacenar los datos de los registros RAWANGLE--------------------------------------------
uint8_t dato1=0;
uint8_t dato2=0;
// --------------------------------------------------------------------------------------------------------
/**
 * @brief Lee un registro de algún de algun dispositivo por i2c
 * 
 * @param slave_addr Dirección del dispositivo
 * @param reg_addr Registro a leer
 * @param data Apuntador donde se guarda el dato leído
 * @param len Longitud de bits
 * @return esp_err_t 
 */
esp_err_t i2c_lectura(uint8_t slave_addr, uint8_t reg_addr, uint8_t *data, uint16_t len)
{
    //agregar un error en dado caso que no se reciba una respuesta por falta de comunicación (Desconectado y si se apunta a un registro que no existe)
    esp_err_t ret;
    i2c_cmd_handle_t cmd = i2c_cmd_link_create();
    i2c_master_start(cmd);
    i2c_master_write_byte(cmd, (slave_addr<<1), 1);
    i2c_master_write_byte(cmd, reg_addr, 1);
    i2c_master_stop(cmd);
    ret = i2c_master_cmd_begin(I2C_NUM_0, cmd, 1000 / portTICK_PERIOD_MS);
    i2c_cmd_link_delete(cmd);
    if (ret != ESP_OK) {
        return ret;
    }
    cmd = i2c_cmd_link_create();
    i2c_master_start(cmd);
    i2c_master_write_byte(cmd, (slave_addr<<1)|1, 1);
    i2c_master_read(cmd, data, len,  I2C_MASTER_LAST_NACK);
    i2c_master_stop(cmd);
    ret = i2c_master_cmd_begin(I2C_NUM_0, cmd, 1000 / portTICK_PERIOD_MS);
    i2c_cmd_link_delete(cmd);
    return ret;
}
/**
 * @brief Escribe un valor a un registro
 * 
 * @param addr Dirección del dispositivo
 * @param reg_addr Registro a escribir
 * @param data Valor a escribir
 */
void i2c_escritura(uint8_t addr,uint8_t reg_addr,uint8_t data){
    i2c_cmd_handle_t cmd = i2c_cmd_link_create();
    i2c_master_start(cmd);
    i2c_master_write_byte(cmd,(addr<<1),0x0);
    i2c_master_write(cmd,&reg_addr,1,0x0);
    i2c_master_write(cmd,&data,1,0x0);
    i2c_master_stop(cmd); 
    i2c_master_cmd_begin(I2C_MASTER_NUM,cmd,I2C_MASTER_TIMEOUT_MS / portTICK_PERIOD_MS);
    i2c_cmd_link_delete(cmd);
}
void ConfiguracionMaxAng(){
    i2c_escritura(ADDR,MANG4b,0x0B);//Los valores escritos para los registros MANG son para limitar el angulo a 0°-260° y aprovechar la máxima resolución
    i2c_escritura(ADDR,MANG8b,0x8E);
    i2c_escritura(ADDR,CONF_REG,0b00010000);
}
void LeerRawAngle(){
    i2c_lectura(ADDR,RAW_ANGLE4b,&dato1,1);     //Lectura por medio de i2c del registro RAWANGLE y almacenados en las variables (dato1 y 2)
    i2c_lectura(ADDR,RAW_ANGLE8b,&dato2,1);
}

void EscribirTramaDeDatosAEncoder(uint8_t reg_addr0,uint8_t reg_addr1,uint8_t dato0,uint8_t dato1){
    i2c_escritura(ADDR,reg_addr0,dato0);
    i2c_escritura(ADDR,reg_addr1,dato1);
}
/**
 * @brief Rutina para la programación del encoder magnético por medio de comunicación i2c
 * 
 */

void RutinaDeConfiguracionManual(){
    //Colocar el indicador en la posición inicial manualmente
    ConfiguracionMaxAng();
    printf("Coloque el indicador en la posicion inicial");
    vTaskDelay(10000 / portTICK_PERIOD_MS);//Esperar 10 segundos para alcanzar a colocarlo manualmente
    LeerRawAngle();
    printf("Leyendo datos del registro RAW_ANGLE \t4b=%i\t8b=%i \n Escribiendo valores de RAW_ANGLE a ZPOS \n",dato1,dato2);
    EscribirTramaDeDatosAEncoder(ZPOS4b,ZPOS8b,dato1,dato2);
    printf("Coloque indicador a posición final en sentido horario");
    vTaskDelay(10000 / portTICK_PERIOD_MS);//Esperar 10 segundos para alcanzar a colocarlo manualmente
    LeerRawAngle();
    printf("Leyendo datos del registro RAW_ANGLE \t4b=%i\t8b=%i \n Escribiendo valores de RAW_ANGLE a MPOS \n",dato1,dato2);
    EscribirTramaDeDatosAEncoder(MPOS4b,MPOS8b,dato1,dato2);

}
void RutinaDeConfiguracionAutomatica(){
    ConfiguracionMaxAng();
    MoverMotorPorTiempo(40,1,100);
    MoverMotorPorTiempo(700,1,25);
    LeerRawAngle();
    EscribirTramaDeDatosAEncoder(ZPOS4b,ZPOS8b,dato1,dato2);
    MoverMotorPorTiempo(40,-1,100);
    MoverMotorPorTiempo(700,-1,25);
    LeerRawAngle();
    EscribirTramaDeDatosAEncoder(MPOS4b,MPOS8b,dato1,dato2);
}

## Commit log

2022-06-15 Create README file
    Se añaden la lista de los primeros componentes
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2022-06-30 Se subio los archivos del codigo generado en PlatformIO y se agregaron los archivos del banco de pruebas del modulo as5600, tanto de Freecad como en STL
    [Base_iman_bal.FCStd, Base_modulo.FCStd, Copia de Indicador_de_grados-Body.stl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]
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2022-07-07 Se crearon los diseños para realizar las pruebas con 4 modulos simultaneamente, además se adjuntan un codigo de prueba usando freertos
    [Ensamble.FCStd, Estructura.FCStd, V1.FCStd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]
2022-09-12 Se cambio el proyecto de Platformio a ESP-IDF
    [080-Body.3mf, 080-Body.stl, 080.FCStd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]
2022-09-14 Se añade documentación
    [Ensamble.FCStd, intermedio-Body.stl, intermedio.FCStd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]
2022-09-14 Se agrega .md para que encuentre el archivo
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2022-09-15 Se agregaron tres modelos para indicador de grados
    [080-Body.3mf, 080-Body.stl, 080.FCStd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]
2022-09-16 Se agrego una configuración automática al encoder y correciones menores a los CAD
    [Base_modulo.FCStd, EngraneApuntador-Fusion.stl, EngraneApuntador.FCStd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]
2022-09-18 Se agregaron y modificaron archivos freecad además se agrego informacióna a FreeRtos.md
    [Ensamble.FCStd, apuntador-Body.stl, apuntador.FCStd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]
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2022-09-19 Cambio de nombre de capeta de codigo y test de construcción
2022-09-19 Cambio de nombre de capeta de codigo y test de construcción 3
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2022-11-02 Creacion de estructuras principales
    [Base_iman_bal.FCStd, Base_modulo.FCStd, Copia de Indicador_de_grados.FCStd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]
2022-11-02 Commit para hacer otra branch y organizar mejor el código
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2022-11-08 Configuracion y funciones ADC
    [Balero_Parametrico.FCStd, Base_iman_bal.FCStd, Base_modulo.FCStd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]
2022-11-09 Se agrego comunicacion i2c y activacion de encoders
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2022-11-11 Correciones del algoritmo de valor mapeado encoder y marcha acoplada
2022-11-12 Se añade una funcion para visualizar la trama de datos
2022-11-13 Organizado el nuevo servo e implementacion basica de freertos
    [Balero_Parametrico.FCStd, EJE_reatroalimentacion.FCStd, Eje parametrico.FCStd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]
2022-11-13 Inicio de esquematicos en kicad
    [CAE32_PCB.kicad_pcb, CAE32_PCB.kicad_sch]
2022-11-14 Se agregaron archivos .md para dar mas informacion
    [CAE32_PCB.kicad_pcb, CAE32_PCB.kicad_sch, dfg.kicad_sch]
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2022-11-19 Actualización del archivo README
    [Analog_Devices_-_AD7788BRM.step, CAE32_PCB.kicad_pcb, CAE32_PCB.kicad_sch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]
2022-11-21 Actualización de README con documentación de dispositivo HID
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2022-12-15 Detección de dispositivos (Joystick, HID)
    [CAE32_PCB.kicad_sch]
2022-12-25 Primer prototipo de PCB
    [CAE32_PCB-B_Cu.gbr, CAE32_PCB-B_Mask.gbr, CAE32_PCB-B_Paste.gbr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]
2022-12-27 Instrucciones para compilar la interfaz y creación de la segunda PCB
    [Modular.kicad_pcb, Modular.kicad_sch, fusible-Part.step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]
2022-12-31 Diseño de Pcb y Boom, de placa de pedales 1.0V
    [CAE32_PCB.kicad_pcb, CAE32_PCB.kicad_sch, EVQPUM02K-Part.step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]
2022-12-31 Actualización de README
    [Boom.csv, Boom.ods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]
2023-01-04 Actualización de Gerbers e indicador de status de conexión
    [Modular-B_Cu.gbr, Modular-B_Mask.gbr, Modular-B_Paste.gbr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]
2023-01-10 Uso de GApplication
    [Balero_Parametrico.FCStd, Base_iman_bal.FCStd, Base_modulo.FCStd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]
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2023-01-21 Visor de cambios terminado y actualización de UI
    [EJE_reatroalimentacion-Body.3mf.amf, EJE_reatroalimentacion.FCStd, Eje_engrane.amf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]
2023-01-27 Prototipo de actualizaciones y 4 ejes en joystick
    [case0.FCStd]
2023-01-30 Correciones de errores PCB:pedales y hall
    [Boom.csv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]
2023-01-31 Ultima revision de PCBs
    [Boom.csv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]
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2023-01-31 Eliminación de imagene que ya no es necesaria
2023-02-03 Limpieza de directorios
    [CAE32_PCB-B_Cu.gbr, CAE32_PCB-B_Mask.gbr, CAE32_PCB-B_Paste.gbr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]
2023-02-04 Se añade un script para crear el acceso directo y mover los archivos al home
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2023-03-16 added esp-idf project for the main board: Spi
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2023-03-21 Correct communication with SPI
    [app_main.c, main.c]
2023-03-27 Stm32 returns ADC values through SPI correctly
    [main.c, pedales.ioc]
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2023-04-17 Fix: Formato de csv
    [First_prototype.csv]
2023-04-17 Refactor: Renombre de carpea de OAA a uno mas descriptivo
    [CAE32_PCB.kicad_pcb, CAE32_PCB.kicad_sch, dfg.kicad_sch]
2023-04-17 Refactor: Renombre de carpeta ElementosExtrasPCB a uno mas descriptivo
    [fusible-Part.step, fusible.FCStd]
2023-04-17 Delete: Se elimina archivos de gerber
    [Boom.csv, Boom.ods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]
2023-04-17 Refactor: Renombre de carpeta Boom a BOM y eliminacion de segundo protipo
    [Modular.csv]
2023-04-17 Refactor: Renombre de carpeta Boom a BOM
    [Boom.csv]
2023-04-17 Refactor: Renombre de carpeta Boom a BOM y eliminacion de archivos csv innecasarios
    [Boom.csv, Pedals.csv]
2023-04-17 Style: Se cambia el formato del csv para que concuerde con los demas
    [Analog_Devices_-_AD7788BRM.step, Modular.csv]
2023-04-17 Delete: Modelos 3d relacionados al componente _UDD32_
    [UDD32-Body.step, UDD32-Part.step, UDD32.FCStd]
2023-04-17 Refactor: Renombre de carpeta de Modelo3D a uno mas descriptivo
    [EVQPUM02K-Part.step, EVQPUM02K.FCStd]
2023-04-17 Update: Cambio de nombre del dispositivo a buscar, de Steering Wheel CAE32 a CAE32 Steering Wheel
2023-04-17 Update:Se crean los archivos donde se declaran las tareas que se ejecutaran
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2023-04-28 Fix: Se corrige el grosor de la pcb a 1.6mm
    [Pedals.kicad_pcb]
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2023-04-28 Fix: Se agrega una nueva regla al Makefile para que genere las carpetas en dado caso que no existan
2023-05-03 Fix: Error al presionar el boton Conectar mas de una vez cuando ya se encontraba conectado el dispositivo
